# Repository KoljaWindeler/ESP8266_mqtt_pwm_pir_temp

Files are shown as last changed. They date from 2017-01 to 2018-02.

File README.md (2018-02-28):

# ESP8266 MQTT Repository

### Folderstructure

HA - Backup of my Homeassistant settings

JKW_MQTT_PWM_PIR_TEMP - The big deal, this is the firmware for the esp units

PCB - Some selfbuild boards based on the esp8266

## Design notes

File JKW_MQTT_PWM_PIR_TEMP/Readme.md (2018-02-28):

V1,V2,V3 are obsolete<br />
V4 is sort of the stable "branch" (killer feature was the peripheral framework)<br />
V5 is the development branch (new feature is the pseudo mesh structure)

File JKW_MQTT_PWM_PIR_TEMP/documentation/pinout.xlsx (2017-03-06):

Pin | Ard | Function | Note | Sonoff Inline box (assumption) | Zwischenstecker | Koljas Platine v2 | Koljas Platine v3
1 | - | VCC |  | - | - | - | -
2 | - | antenna |  | - | - | - | -
3 | - | VCC |  | - | - | - | -
4 | - | VCC |  | - | - | - | -
5 | - | rtc-vcc |  | - | - | - | -
6 | A0 | tout |  | nur MCU pin | nur MCU pin |  | Analog measurement
7 | - | e-en | 10k pullup, keine Weiterverwendung moeglich | - | - | - | -
8 | D0 | xpd-DCDC/GP16 | Deepsleepwakeup | - | - | - | PWM dimming 3
9 | D5 | SCL/MTMS/GP14 |  | an der Pfostenleiste (PIR) | nur MCU Pin | ? | PIR
10 | D6 | PWM0/MTDI/GP12 |  | am Relayschalter (Nmosfet) | zusatzlich LED1 | DS18B20 | am Relayschalter (Nmosfet)
11 | - | VCC |  | - | - | - | -
12 | D7 | PWM1/MTCK/GP13 | Useable as PWM out? | LED | LED (Modified DS18B20) | Relais | DS18B20
13 | D8 | PWM2/MTDO/GP15 | has to be low on startup! | 10k pulldown | 10k pulldown | 10k pulldown | 10k pulldown / Power for adc
14 | D4 | SDA/GP2 |  | nur MCU pin | nur MCU pin | DHT | DHT
15 | D3 | E-FW/SPICS2/GP0 |  | Pullup + S1 taster |  | switch | switch
16 | D2 | NC/GP4 |  | nur MCU pin | nur MCU pin | PWM dimming | PWM dimming 1
17 | - | VCC |  | - | - | - | -
18 | - | E-D2/GP9 | Flash | Flash | Flash | Flash | Flash
19 | - | E-D3/GP10 | Flash | Flash | Flash | Flash | Flash
20 | - | E-CMD/GP11 | Flash | Flash | Flash | Flash | Flash
21 | - | E-CLK/GP6 | Flash | Flash | Flash | Flash | Flash
22 | - | E-D0/GP7 | Flash | Flash | Flash | Flash | Flash
23 | - | E-D1/GP8 | Flash | Flash | Flash | Flash | Flash
24 | D1 | NC/GP5 |  | nur MCU pin (use a PIR?) | nur MCU pin (use a PIR?) | PIR | PWM dimming 2
25 | D9 | E-RX/GP3 | kann man nehmen wenn kein debug noetig ist | an Pfostenleiste, Uart | an Pfostenleiste, Uart | an Pfostenleiste, Uart | an Pfostenleiste, Uart
26 | D10 | E-TX/GP1 | kann man nehmen wenn kein debug noetig ist | an Pfostenleiste, Uart | an Pfostenleiste, Uart | an Pfostenleiste, Uart | an Pfostenleiste, Uart
27 | - | CLk |  | - | - | - | -
28 | - | CLK |  | - | - | - | -
29 | - | VCC |  | - | - | - | -
30 | - | VCC |  | - | - | - | -
31 | - | Res12k |  | - | - | - | -
32 | - | E-RST | 10k pullup, keine Weiterverwendung | - | - | - | -
33 |  | GND

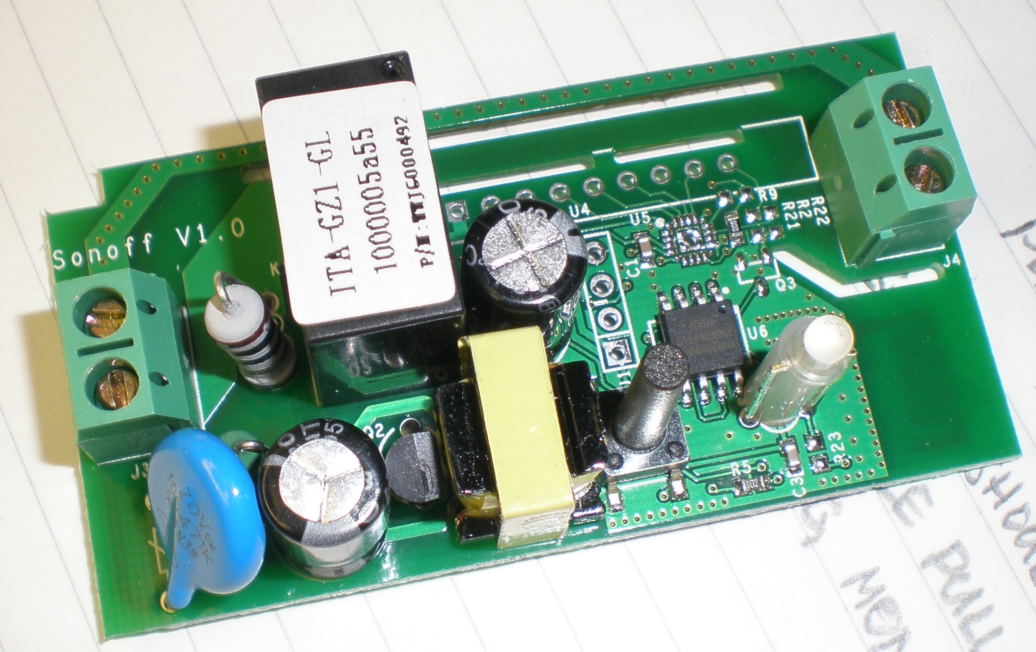
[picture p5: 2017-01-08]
JKW_MQTT_PWM_PIR_TEMP/documentation/sonoff_v1-top-oblique.png

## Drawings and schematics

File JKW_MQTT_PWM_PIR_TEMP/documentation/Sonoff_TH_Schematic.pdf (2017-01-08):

# VCC-3V3 E-FW

# VCC-3V3

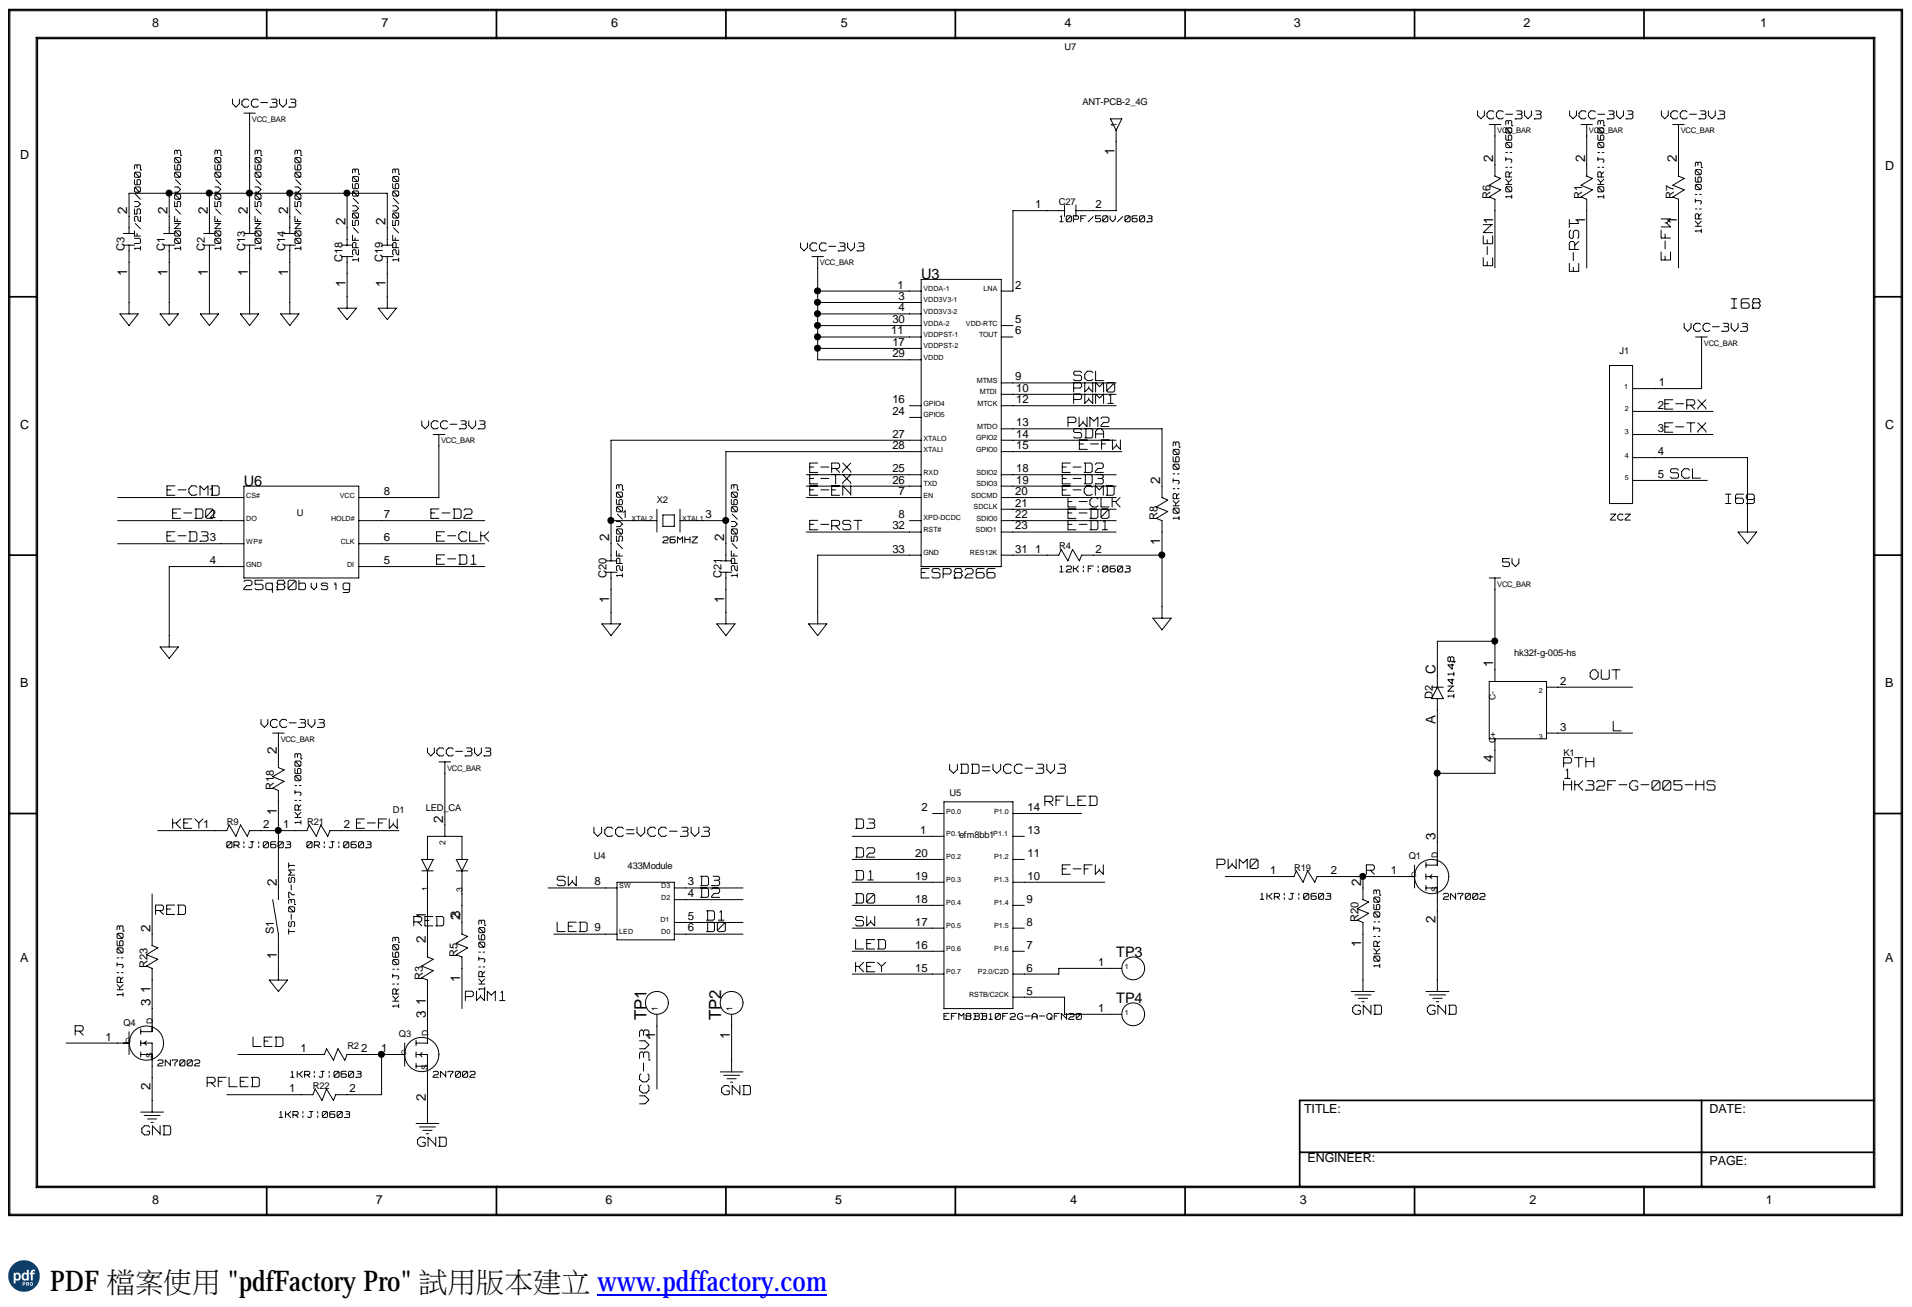
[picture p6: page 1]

TITLE: | DATE:

ENGINEER: | PAGE:

PDF 檔案使用 "pdfFactory Pro" 試用版本建立 www.pdffactory.com

330UH/0410

L1

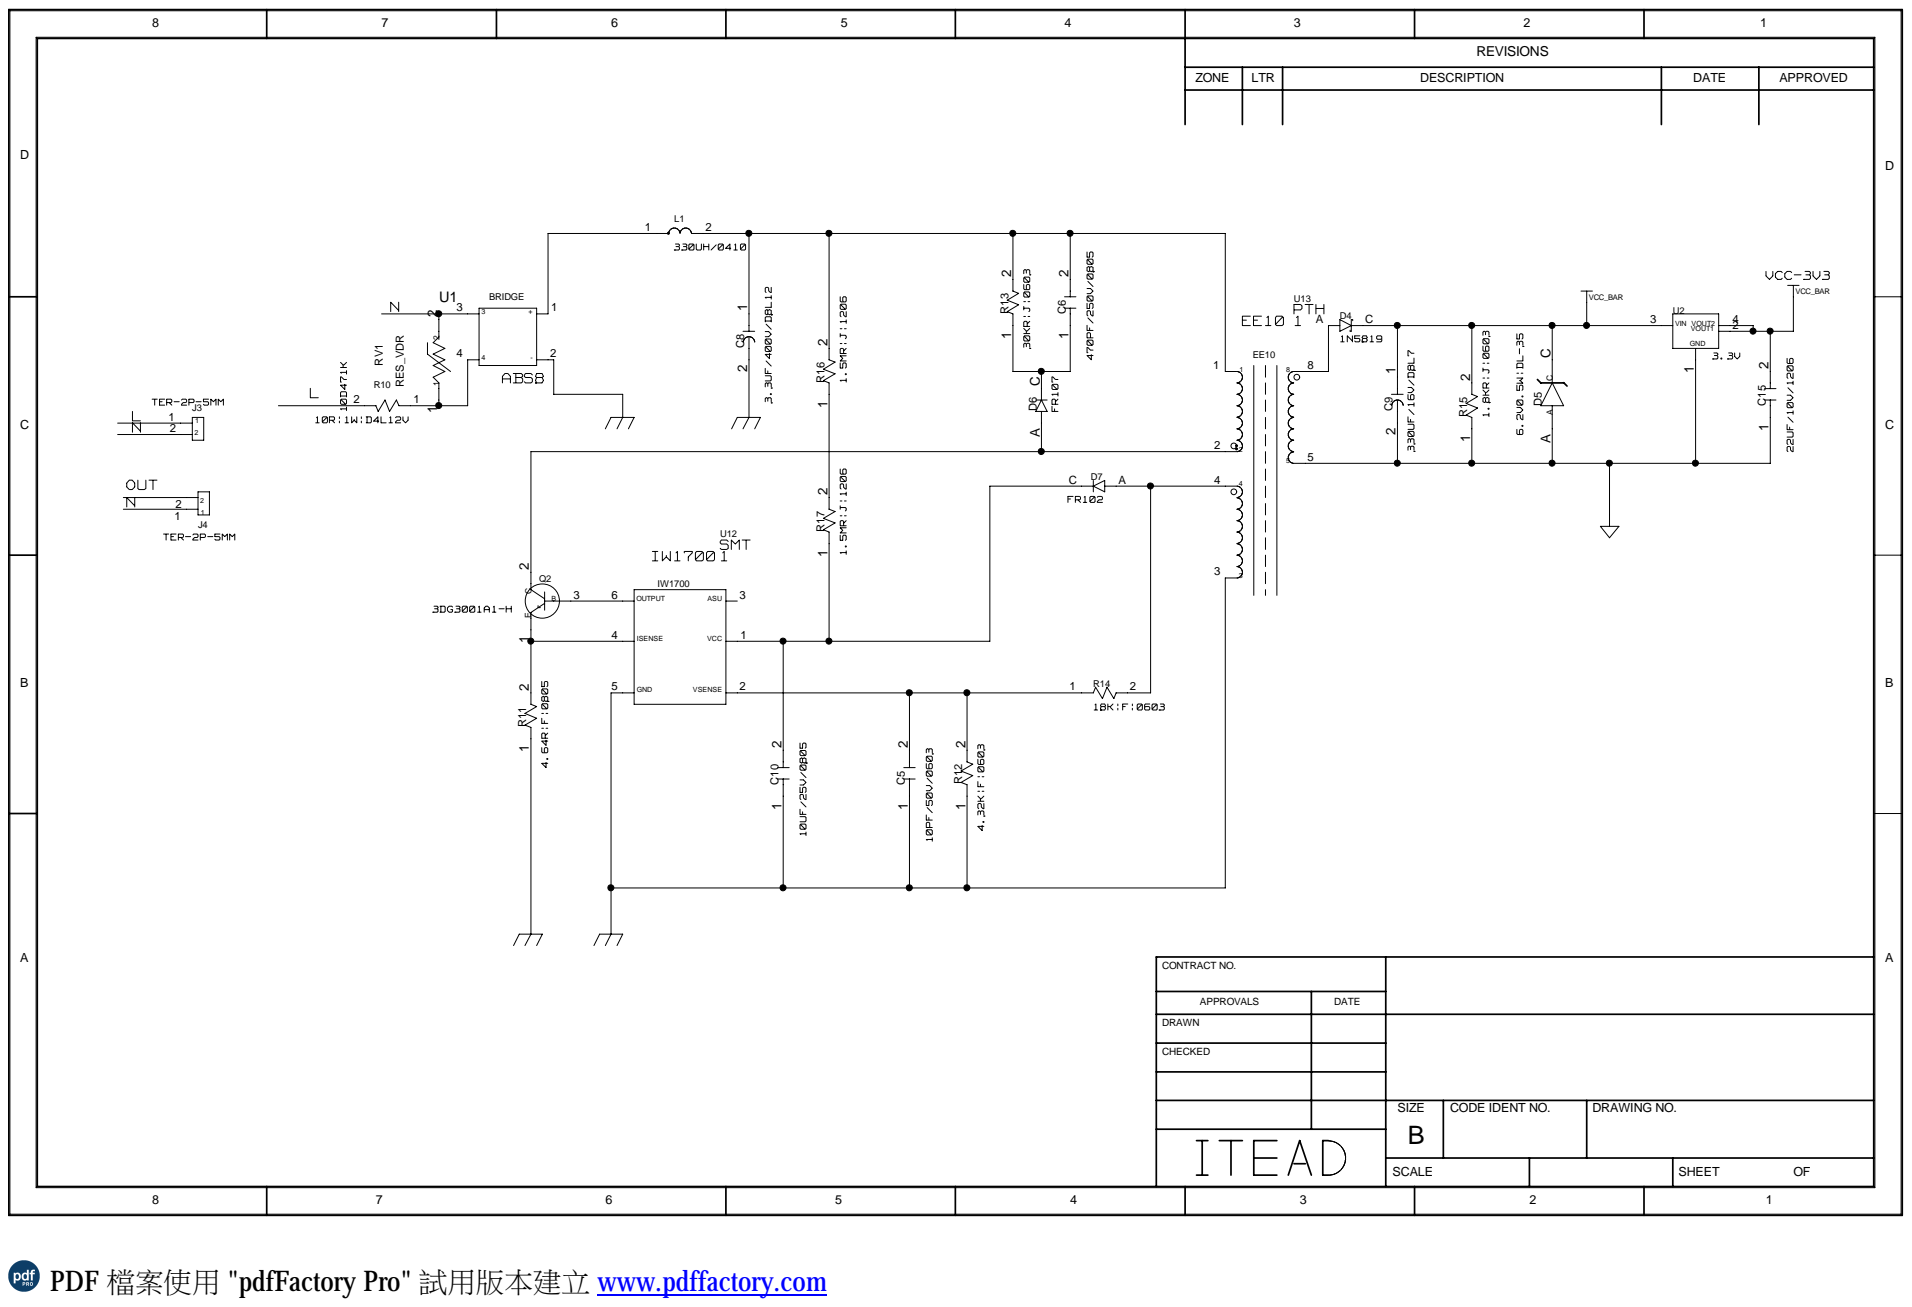
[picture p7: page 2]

PDF 檔案使用 "pdfFactory Pro" 試用版本建立 www.pdffactory.com

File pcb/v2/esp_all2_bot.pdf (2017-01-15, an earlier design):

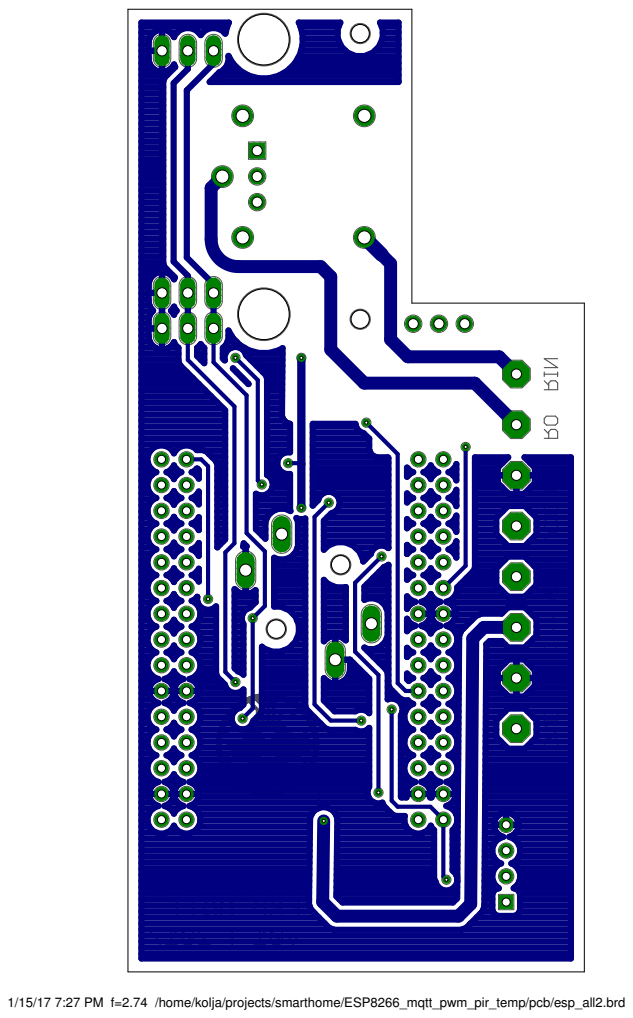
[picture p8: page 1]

1/15/17 7:27 PM f=2.74 /home/kolja/projects/smarthome/ESP8266_mqtt_pwm_pir_temp/pcb/esp_all2.brd

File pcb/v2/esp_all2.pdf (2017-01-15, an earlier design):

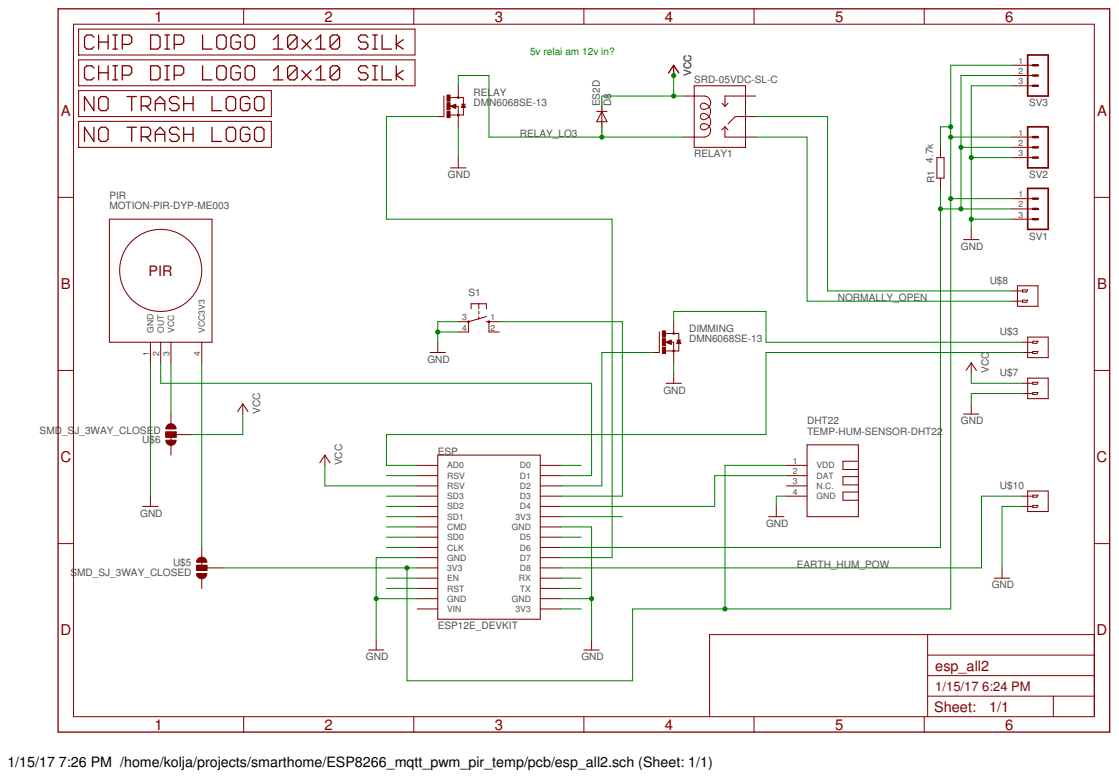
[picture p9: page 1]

1/15/17 7:26 PM /home/kolja/projects/smarthome/ESP8266_mqtt_pwm_pir_temp/pcb/esp_all2.sch (Sheet: 1/1)

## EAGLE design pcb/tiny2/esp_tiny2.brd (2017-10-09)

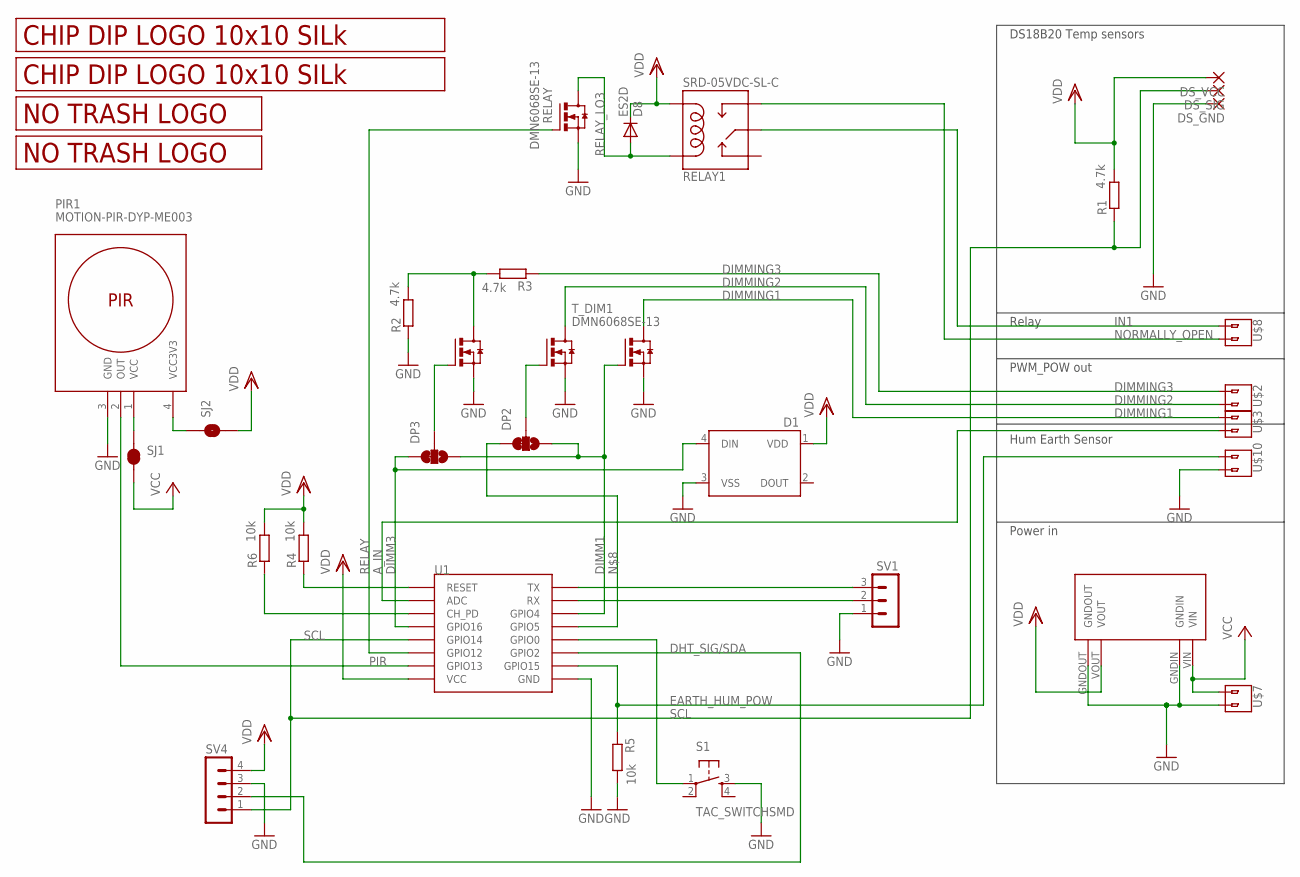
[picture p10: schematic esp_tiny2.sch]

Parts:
D1: WS2812B
D8: ES2D; SMB
DP2, DP3: SMD_SJ_3WAY_CLOSED
DS_GND: SMD2; SMD1,27-2,54
DS_SIG: SMD2; SMD1,27-2,54
DS_VCC: SMD2; SMD1,27-2,54
PIR1: MOTION-PIR-DYP-ME003; MOTION-PIR-DYP-ME003_FRAMELESS
R1, R2, R3: 4.7k; M0805
R4, R5, R6: 10k; M0805
RELAY: DMN6068SE-13; SOT223
RELAY1: SRD-05VDC-SL-C
S1: TAC_SWITCHSMD; TACTILE-SWITCH-SMD
SJ1: SMD_SJ_2WAY_CLOSEDCLOSED; SMD_SJ_2WAY_CLOSED
SJ2: SMD_SJ_2WAY_OPEN
SV1: MA03-1
SV4: MA04-1
T_DIM1, T_DIM2, T_DIM3: DMN6068SE-13; SOT223
U1: ESP12SMD; ESP12-SMD
U$1, U$11: LOGO_10X10_SILK; LOGO2_10X10_SILK
U$2, U$3, U$7, U$8, U$10: V1; 2_SCREW_PIN
U$4: LOGO_NO_TRASHNO_TRASH; LOGO_ROHS_NO_TRASH
U$9: LOGO_NO_TRASHROHS; LOGO_ROHS_SYM
U$12: MP1584EN

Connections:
3.3V_PIR: PIR1.4 (VCC3V3), SJ2.1
12V_PIR: PIR1.1 (VCC), SJ1.1
A_IN: U1.ADC, U$3.P$2 (2)
DHT_SIG/SDA: SV4.2, U1.GPIO2
DIMM1: DP2.3, DP3.3, T_DIM1.1 (G), U1.GPIO4
DIMM3: D1.4 (DIN), DP3.1, U1.GPIO16
DIMMING1: T_DIM1.2 (D), T_DIM1.4 (D), U$3.P$1 (1)
DIMMING2: T_DIM2.2 (D), T_DIM2.4 (D), U$2.P$2 (2)
DIMMING3: R3.1, U$2.P$1 (1)
EARTH_HUM_POW: R5.1, U1.GPIO15, U$10.P$1 (1)
GND: D1.3 (VSS), DS_GND.1, PIR1.3 (GND), R2.1, R5.2, RELAY.3 (S), S1.3, SV1.1, SV4.3, T_DIM1.3 (S), T_DIM2.3 (S), T_DIM3.3 (S), U1.GND, U$7.P$2 (2), U$10.P$2 (2), U$12.GNDIN, U$12.GNDOUT
IN1: RELAY1.SWCOMMON, U$8.P$1 (1)
unnamed: R6.1, U1.CH_PD
unnamed: R4.1, U1.RESET
unnamed: R2.2, R3.2, T_DIM3.2 (D), T_DIM3.4 (D)
unnamed: SV1.3, U1.TXD0 (TX)
unnamed: SV1.2, U1.RXD0 (RX)
unnamed: S1.1, U1.GPIO0
unnamed: DP2.1, U1.GPIO5
unnamed: DP3.2, T_DIM3.1 (G)
unnamed: DP2.2, T_DIM2.1 (G)
NORMALLY_OPEN: RELAY1.SWOPEN, U$8.P$2 (2)
PIR: PIR1.2 (OUT), U1.GPIO13
RELAY: RELAY.1 (G), U1.GPIO12
RELAY_LO3: D8.A, RELAY.2 (D), RELAY.4 (D), RELAY1.COIL1
SCL: DS_SIG.1, R1.1, SV4.1, U1.GPIO14
VCC: SJ1.3, U$7.P$1 (1), U$12.VIN
VDD: D1.1 (VDD), D8.C, DS_VCC.1, R1.2, R4.2, R6.2, RELAY1.COIL0, SJ2.3, SV4.4, U1.VCC, U$12.VOUT

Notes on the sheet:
DS18B20 Temp sensors
Relay
PWM_POW out
Hum Earth Sensor
Power in

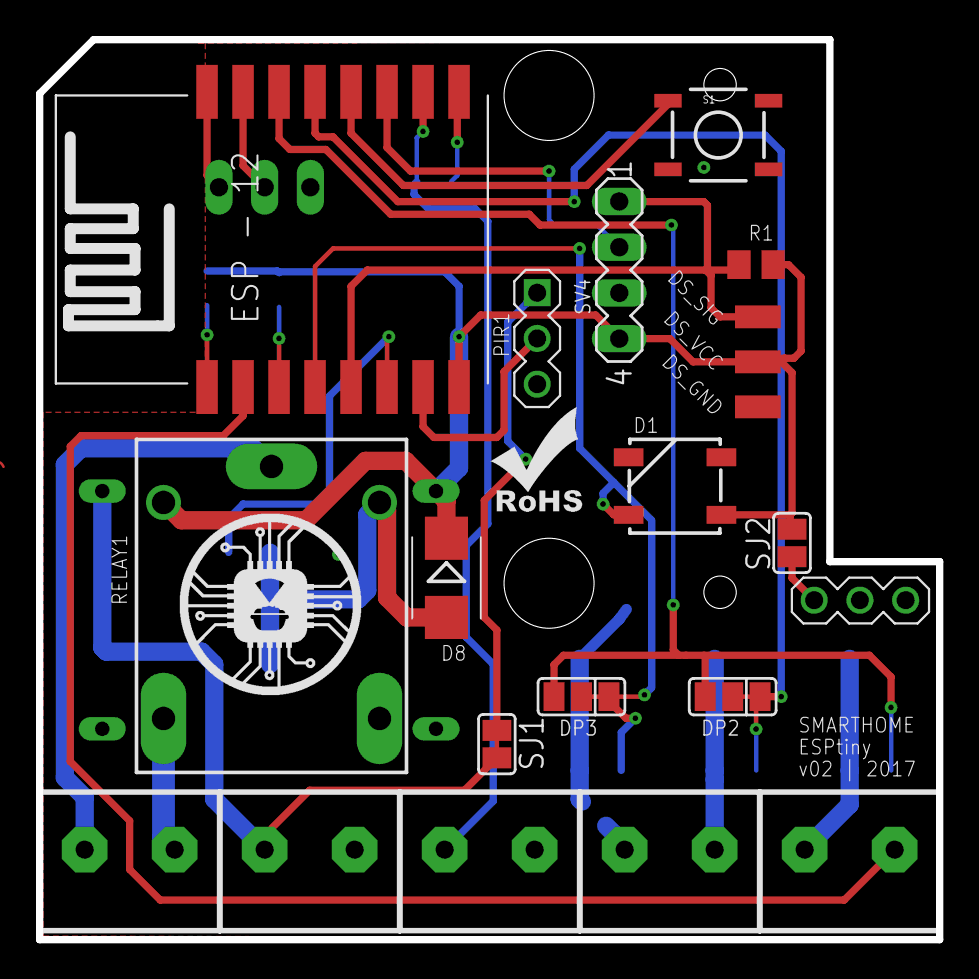
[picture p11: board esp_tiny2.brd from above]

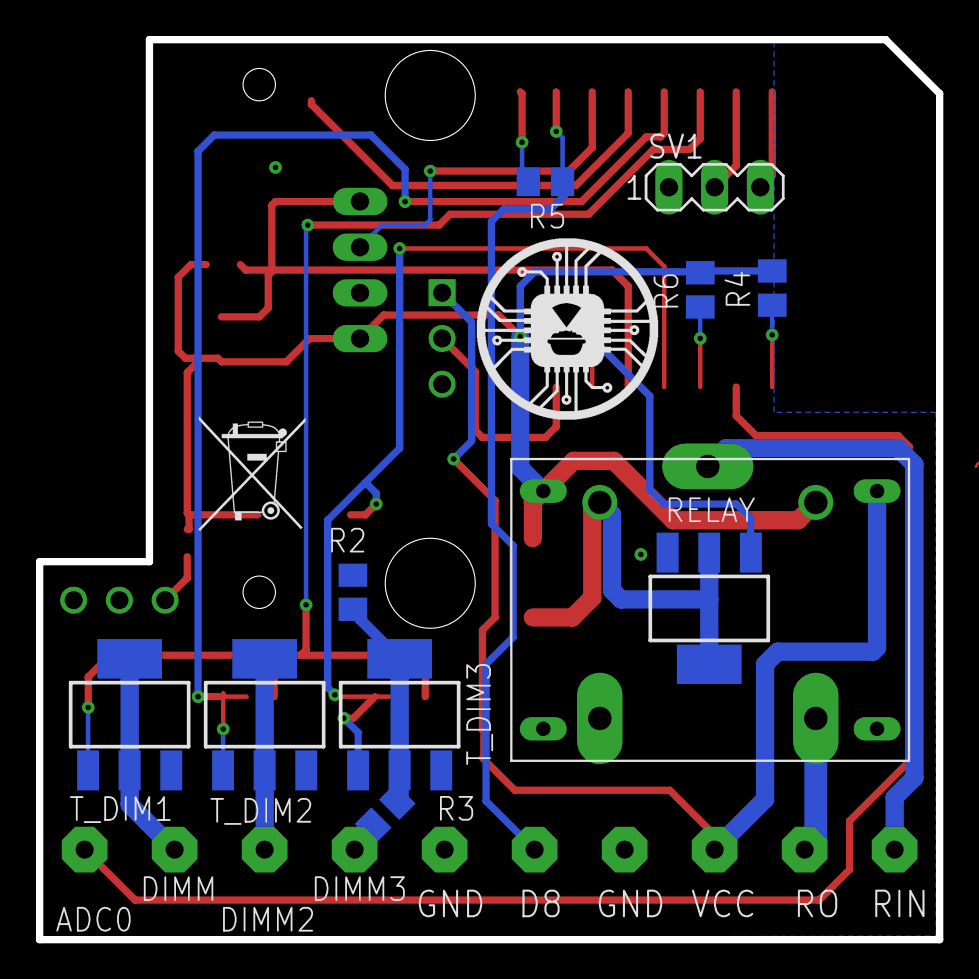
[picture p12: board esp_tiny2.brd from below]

Board: 2 copper layers, 50.0 x 50.0 mm, 35 parts (13 on the bottom side), 28 nets.

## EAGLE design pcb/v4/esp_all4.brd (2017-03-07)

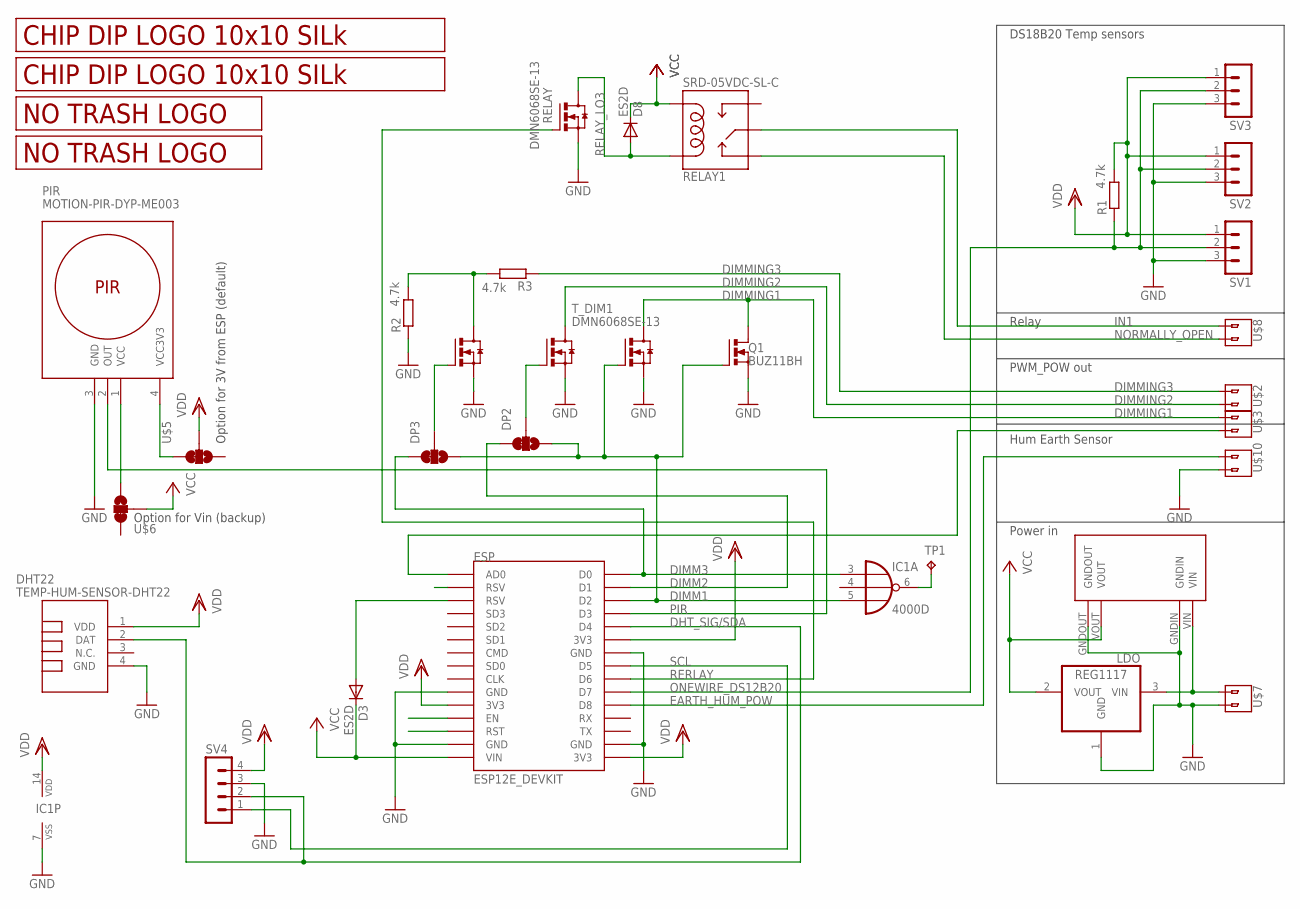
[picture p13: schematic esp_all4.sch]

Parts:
D3, D8: ES2D; SMB
DHT22: TEMP-HUM-SENSOR-DHT22
DP2, DP3: SMD_SJ_3WAY_CLOSED
ESP: ESP12E_DEVKIT
IC1: 4000D; SO14
LDO: REG1117; SOT223
PIR: MOTION-PIR-DYP-ME003
Q1: BUZ11BH; TO220BH
R1, R2, R3: 4.7k; M0805
RELAY: DMN6068SE-13; SOT223
RELAY1: SRD-05VDC-SL-C
SV1, SV2, SV3: MA03-1
SV4: MA04-1
TP1: TPTP20SQ; TP20SQ
T_DIM1, T_DIM2, T_DIM3: DMN6068SE-13; SOT223
U$1, U$11: LOGO_10X10_SILK; LOGO2_10X10_SILK
U$2, U$3, U$7, U$8, U$10: V1; 2_SCREW_PIN
U$4: LOGO_NO_TRASHNO_TRASH; LOGO_ROHS_NO_TRASH
U$5, U$6: SMD_SJ_3WAY_CLOSED
U$9: LOGO_NO_TRASHROHS; LOGO_ROHS_SYM
U$12: MP1584EN_FRAMELESS

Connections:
DHT_SIG/SDA: DHT22.2 (DAT), ESP.D4, ESP.D41 (D4), SV4.2
DIMM1: DP2.3, DP3.3, ESP.D2, ESP.D21 (D2), IC1.5 (I2), Q1.G, T_DIM1.1 (G)
DIMM2: DP2.1, ESP.D1, ESP.D11 (D1)
DIMM3: DP3.1, ESP.D0, ESP.D01 (D0), IC1.3 (I0)
DIMMING1: Q1.D, T_DIM1.2 (D), T_DIM1.4 (D), U$3.P$1 (1)
DIMMING2: T_DIM2.2 (D), T_DIM2.4 (D), U$2.P$2 (2)
DIMMING3: R3.1, U$2.P$1 (1)
EARTH_HUM_POW: ESP.D8, ESP.D81 (D8), U$10.P$1 (1)
GND: DHT22.4 (GND), ESP.GND@0 (GND), ESP.GND@1 (GND), ESP.GND@2 (GND), ESP.GND@3 (GND), ESP.GND@4 (GND), ESP.GND@5 (GND), ESP.GND@6 (GND), ESP.GND@7 (GND), IC1.7 (VSS), LDO.1 (GND), PIR.3 (GND), Q1.S, R2.1, RELAY.3 (S), SV1.3, SV2.3, SV3.3, SV4.3, T_DIM1.3 (S), T_DIM2.3 (S), T_DIM3.3 (S), U$7.P$2 (2), U$10.P$2 (2), U$12.GNDIN, U$12.GNDOUT
IN1: RELAY1.SWCOMMON, U$8.P$1 (1)
unnamed: ESP.AD0, ESP.AD1 (AD0), U$3.P$2 (2)
unnamed: ESP.RSV@0 (RSV), ESP.RSV@01 (RSV)
unnamed: R2.2, R3.2, T_DIM3.2 (D), T_DIM3.4 (D)
unnamed: IC1.6 (O), TP1.TP
unnamed: ESP.EN, ESP.EN1 (EN)
unnamed: ESP.RST, ESP.RST1 (RST)
unnamed: D3.A, ESP.RSV@1 (RSV), ESP.RSV@11 (RSV)
unnamed: LDO.3 (VIN), U$7.P$1 (1), U$12.VIN
unnamed: DP3.2, T_DIM3.1 (G)
unnamed: DP2.2, T_DIM2.1 (G)
unnamed: PIR.4 (VCC3V3), U$5.1
unnamed: PIR.1 (VCC), U$6.3
NORMALLY_OPEN: RELAY1.SWCLOSED (SWCLOSE), U$8.P$2 (2)
ONEWIRE_DS12B20: ESP.D7, ESP.D71 (D7), R1.1, SV1.2, SV2.2, SV3.2
PIR: ESP.D3, ESP.D31 (D3), PIR.2 (OUT)
RELAY_LO3: D8.A, RELAY.2 (D), RELAY.4 (D), RELAY1.COIL1
RERLAY: ESP.D6, ESP.D61 (D6), RELAY.1 (G)
SCL: ESP.D5, ESP.D51 (D5), SV4.1
VCC: D3.C, D8.C, ESP.VIN, ESP.VIN1 (VIN), LDO.2 (VOUT), RELAY1.COIL0, U$6.2, U$12.VOUT
VDD: DHT22.1 (VDD), ESP.3V3@0 (3V3), ESP.3V3@1 (3V3), ESP.3V3@2 (3V3), ESP.3V3@3 (3V3), ESP.3V3@4 (3V3), ESP.3V3@5 (3V3), IC1.14 (VDD), R1.2, SV1.1, SV2.1, SV3.1, SV4.4, U$5.2

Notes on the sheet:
DS18B20 Temp sensors
Relay
PWM_POW out
Hum Earth Sensor
Power in
Option for 3V from ESP (default)
Option for Vin (backup)

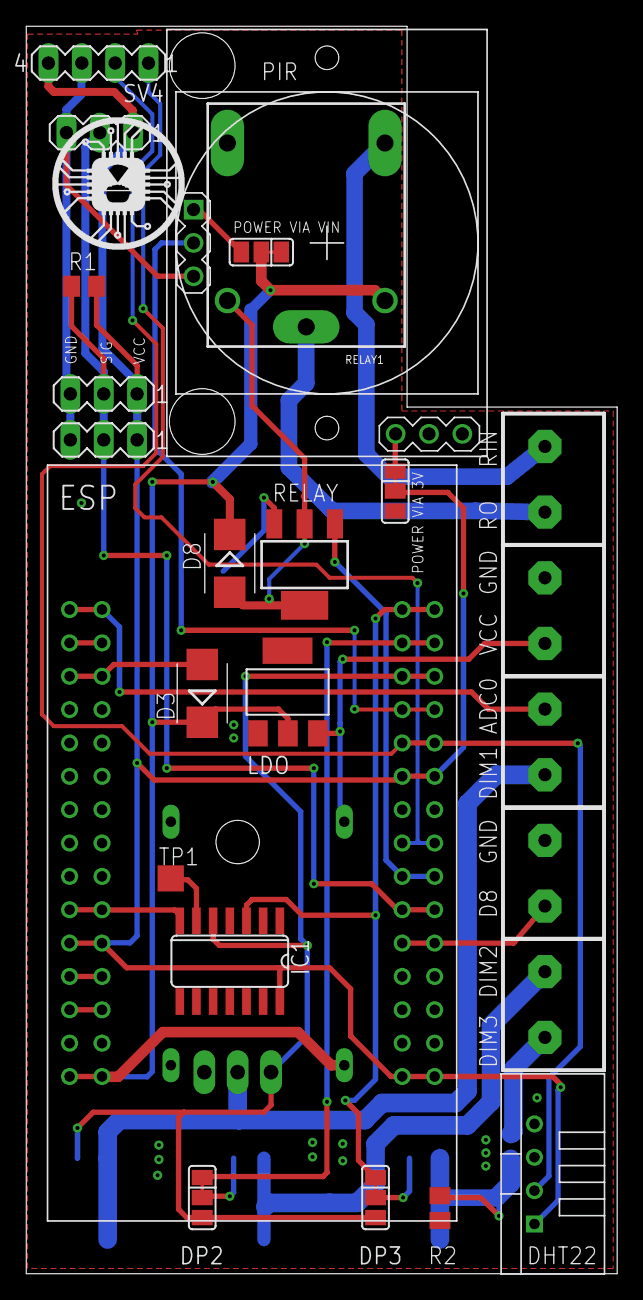
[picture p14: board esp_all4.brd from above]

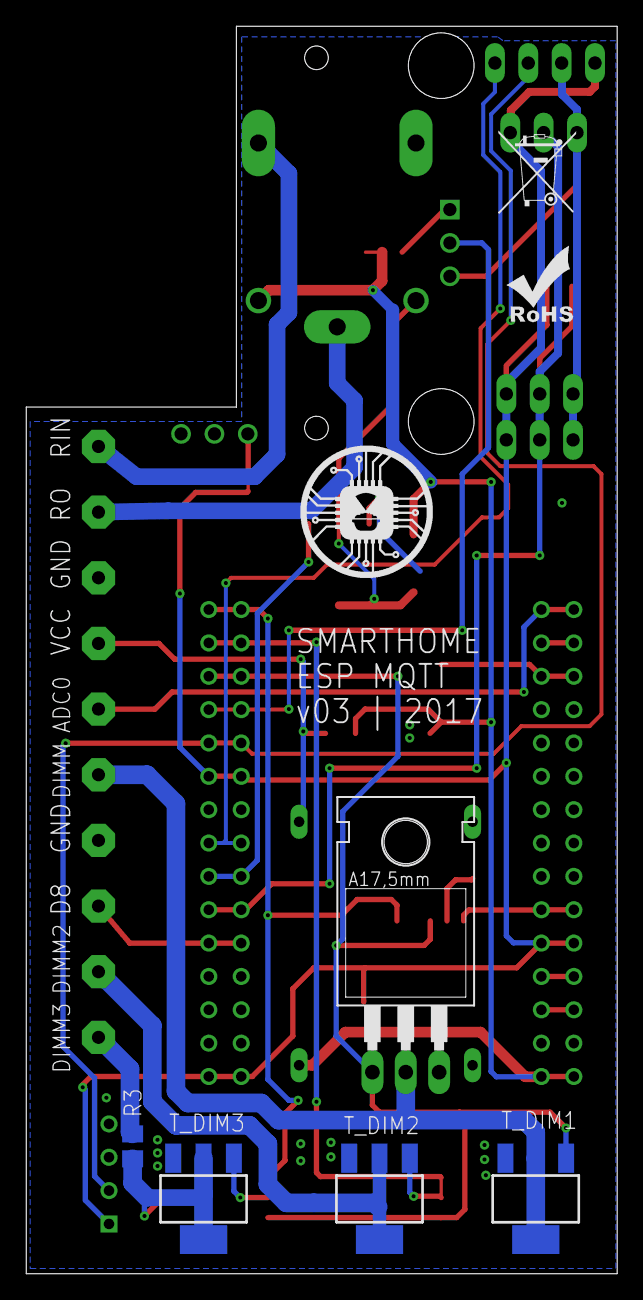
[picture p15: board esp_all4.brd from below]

Board: 2 copper layers, 45.0 x 95.0 mm, 35 parts (9 on the bottom side), 30 nets.

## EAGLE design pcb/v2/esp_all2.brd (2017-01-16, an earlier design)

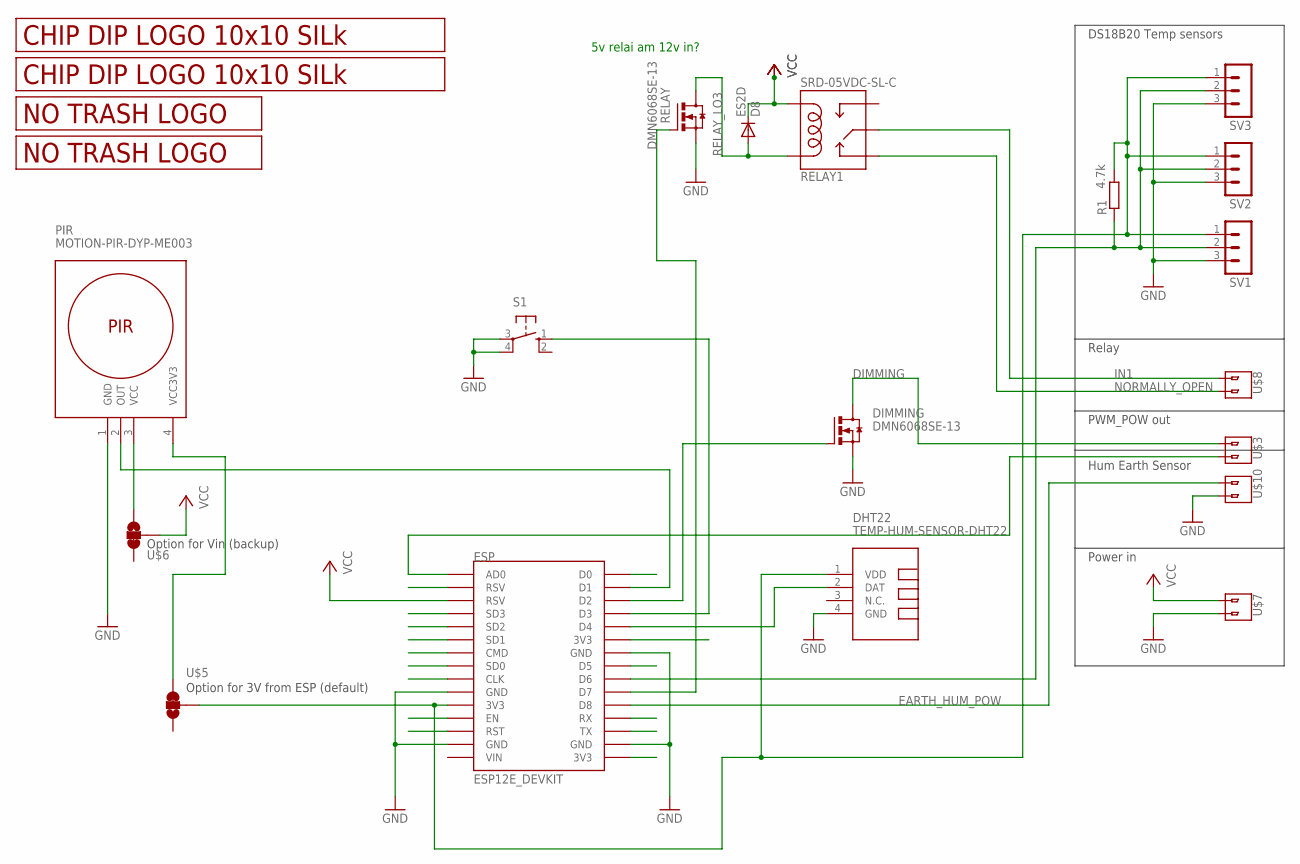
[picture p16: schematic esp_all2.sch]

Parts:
D8: ES2D; SMB
DHT22: TEMP-HUM-SENSOR-DHT22
DIMMING: DMN6068SE-13; SOT223
ESP: ESP12E_DEVKIT
PIR: MOTION-PIR-DYP-ME003
R1: 4.7k; M0805
RELAY: DMN6068SE-13; SOT223
RELAY1: SRD-05VDC-SL-C
S1: 40/XX; B3F/40XX
SV1, SV2, SV3: MA03-1
U$1, U$11: LOGO_10X10_SILK; LOGO2_10X10_SILK
U$3, U$7, U$8, U$10: V1; 2_SCREW_PIN
U$4: LOGO_NO_TRASHNO_TRASH; LOGO_ROHS_NO_TRASH
U$5, U$6: SMD_SJ_3WAY_CLOSED
U$9: LOGO_NO_TRASHROHS; LOGO_ROHS_SYM

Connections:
DIMMING: DIMMING.2 (D), DIMMING.4 (D), U$3.P$1 (1)
EARTH_HUM_POW: ESP.D8, ESP.D81 (D8), U$10.P$1 (1)
GND: DHT22.4 (GND), DIMMING.3 (S), ESP.GND@0 (GND), ESP.GND@1 (GND), ESP.GND@2 (GND), ESP.GND@3 (GND), ESP.GND@4 (GND), ESP.GND@5 (GND), ESP.GND@6 (GND), ESP.GND@7 (GND), PIR.1 (GND), RELAY.3 (S), S1.3, S1.4 (P1), SV1.3, SV2.3, SV3.3, U$7.P$2 (2), U$10.P$2 (2)
IN1: RELAY1.SWCOMMON, U$8.P$1 (1)
unnamed: ESP.AD0, ESP.AD1 (AD0), U$3.P$2 (2)
unnamed: ESP.RSV@0 (RSV), ESP.RSV@01 (RSV)
unnamed: ESP.SD3, ESP.SD32 (SD3)
unnamed: ESP.SD2, ESP.SD22 (SD2)
unnamed: ESP.SD1, ESP.SD12 (SD1)
unnamed: ESP.CMD, ESP.CMD1 (CMD)
unnamed: ESP.SD0, ESP.SD01 (SD0)
unnamed: ESP.CLK, ESP.CLK1 (CLK)
unnamed: ESP.D7, ESP.D71 (D7), RELAY.1 (G)
unnamed: ESP.EN, ESP.EN1 (EN)
unnamed: ESP.RST, ESP.RST1 (RST)
unnamed: ESP.D6, ESP.D61 (D6), R1.1, SV1.2, SV2.2, SV3.2
unnamed: ESP.TX, ESP.TX1 (TX)
unnamed: ESP.RX, ESP.RX1 (RX)
unnamed: ESP.D5, ESP.D51 (D5)
unnamed: PIR.4 (VCC3V3), U$5.1
unnamed: DHT22.1 (VDD), ESP.3V3@0 (3V3), ESP.3V3@3 (3V3), ESP.3V3@4 (3V3), ESP.3V3@5 (3V3), R1.2, SV1.1, SV2.1, SV3.1, U$5.2
unnamed: DHT22.2 (DAT), ESP.D4, ESP.D41 (D4)
unnamed: ESP.D3, ESP.D31 (D3), S1.1 (S)
unnamed: DIMMING.1 (G), ESP.D2, ESP.D21 (D2)
unnamed: ESP.D1, ESP.D11 (D1), PIR.2 (OUT)
unnamed: ESP.D0, ESP.D01 (D0)
unnamed: PIR.3 (VCC), U$6.3
NORMALLY_OPEN: RELAY1.SWCLOSED (SWCLOSE), U$8.P$2 (2)
RELAY_LO3: D8.A, RELAY.2 (D), RELAY.4 (D), RELAY1.COIL1
VCC: D8.C, ESP.RSV@1 (RSV), ESP.RSV@11 (RSV), RELAY1.COIL0, U$6.2, U$7.P$1 (1)

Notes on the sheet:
5v relai am 12v in?
DS18B20 Temp sensors
Relay
PWM_POW out
Hum Earth Sensor
Power in
Option for 3V from ESP (default)
Option for Vin (backup)

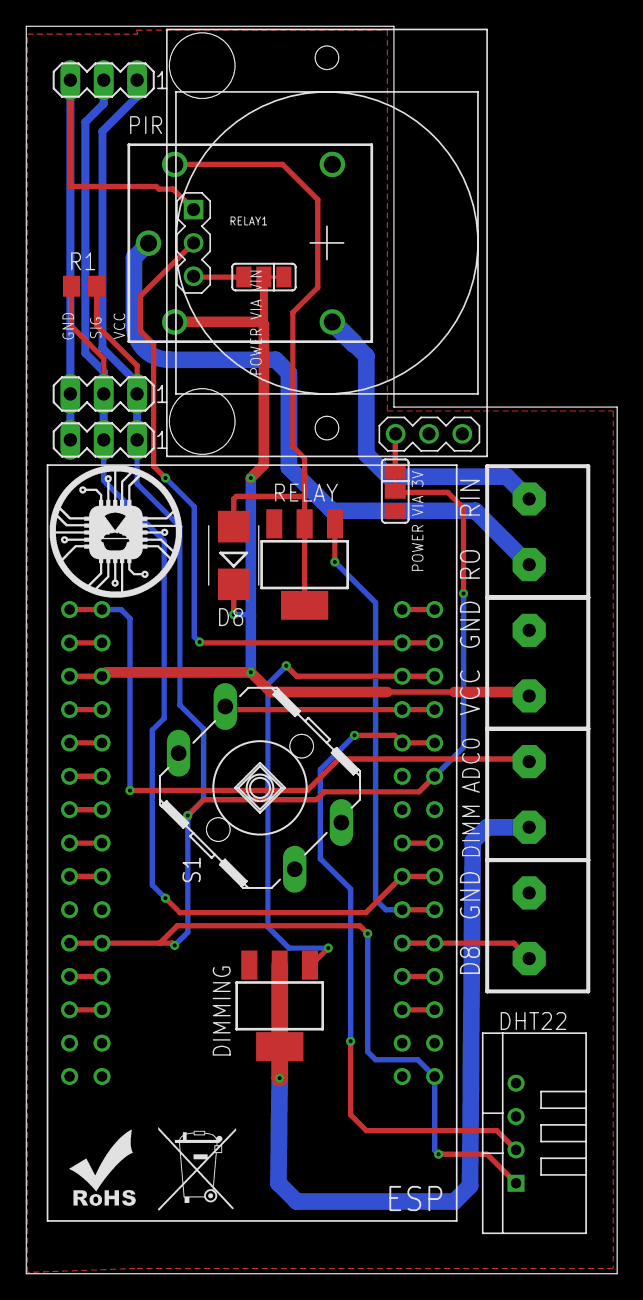
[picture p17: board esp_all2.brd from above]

Board: 2 copper layers, 45.0 x 95.0 mm, 22 parts (1 on the bottom side), 30 nets.

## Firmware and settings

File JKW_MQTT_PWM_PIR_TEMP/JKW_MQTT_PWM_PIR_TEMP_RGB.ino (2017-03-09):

/*
	Highly based on a combination of different version of
	https://github.com/mertenats/Open-Home-Automation/tree/master/ha_mqtt_binary_sensor_pir
	Also using https://github.com/tzapu/WiFiManager

	Configuration (HA) :
	  light:
	  
	 #######  single CHANNEL ################### 
  - platform: mqtt ### tower living
    name: "dev1"
    state_topic: "dev1/PWM_light/status"
    command_topic: "dev1/PWM_dimm/switch"
    brightness_state_topic: 'dev1/PWM_light/brightness'
	## use the line below for dimming
	brightness_command_topic: 'dev1/PWM_dimm/brightness/set'
	## use the line below for setting hard 
	# brightness_command_topic: 'dev1/PWM_light/brightness/set'
    qos: 0
    payload_on: "ON"
    payload_off: "OFF"
    optimistic: false
    brightness_scale: 99
	#######  single CHANNEL ###################
	#######  rgb CHANNEL ################### 
  - platform: mqtt ### tower living
    name: "dev1"
    state_topic: "dev1/PWM_light/status"
    command_topic: "dev1/PWM_dimm/switch"
    brightness_state_topic: 'dev1/PWM_light/brightness'
	rgb_state_topic: 'dev1/PWM_RGB_dimm/color/set'
	## use the lines below for dimming
    brightness_command_topic: 'dev1/PWM_dimm/brightness/set'
	rgb_command_topic: 'dev1/PWM_RGB_dimm/color/set'
	## use the lines below for setting
	# brightness_command_topic: 'dev1/PWM_light/brightness/set'
	# rgb_command_topic: 'dev1/PWM_RGB_light/color/set'
    qos: 0
    payload_on: "ON"
    payload_off: "OFF"
    optimistic: false
    brightness_scale: 99
	#######  rgb CHANNEL ###################

  config for sonoff modules:
  generic 8266
  DIO flash mode
  flash 40 mhz, cpu 80mhz 
  flash size 1mb, 64k filesystem

  This sketch (2017/01/21): 333k (Basic wifi sketch 230k)

  requires arduino libs:
  - adafruit unified sensor
  - adafruit dht22
  - onewire
*/

#include <ESP8266WiFi.h>
#include "WiFiManager.h" // local modified version          //https://github.com/tzapu/WiFiManager WiFi Configuration Magic
#include <PubSubClient.h>
#include <OneWire.h>
#include <EEPROM.h>
#include <DHT.h>
#include <Wire.h>

//////////////////////////////////////////////////// defines //////////////////////////////////////////////
#define SERIAL_DEBUG
#define DIMM_DONE 	        0 // state defs
#define DIMM_DIMMING 	      1 // state defs
#define DHT_def             1
#define DS_def              2
#define CONFIG_SSID         "OPEN_ESP_CONFIG_AP" // SSID of the configuration mode
#define MAX_AP_TIME         300 // restart eps after 300 sec in config mode
#define TEMP_MAX            50 // DS18B20 repoorts 85.0 on first reading ... for whatever reason
// pins
#define PINOUT_SONOFF 1     // set this to "#define" for the sonoff
//#define PINOUT_KOLJA_V2         // set this to "#define" for the pcb firmware .. incosistent pinout
// D8 war nicht so gut ... startet nicht mehr 
#ifdef PINOUT_SONOFF
	#define SIMPLE_LIGHT_PIN  12 // D6
	#define DS_PIN            13 // D7
  #define PIR_PIN           14 // D5
#endif 
#ifdef PINOUT_KOLJA_V2
	#define SIMPLE_LIGHT_PIN  13 // D7
	#define DS_PIN            12 // D6
  #define PIR_PIN            5 // D1
#endif 
#define PWM_LIGHT_PIN1       4  // D2
#define PWM_LIGHT_PIN2       5  // D1
#define PWM_LIGHT_PIN3       16  // D0

#define BUTTON_INPUT_PIN    0  // D3
#define DHT_PIN             2  // D4
#define GPIO_D8             15 // D8


#define BUTTON_TIMEOUT      1500 // max 1500ms timeout between each button press to count up (start of config)
#define BUTTON_DEBOUNCE     200 // ms debouncing for the botton
#define MSG_BUFFER_SIZE     60 // mqtt messages max char size

#define TOTAL_PERIODIC_SLOTS  5 // 5 sensors: adc, rssi, dht_hum, dht_temp, ds18b20
#define UPDATE_PERIODIC       60000/TOTAL_PERIODIC_SLOTS // update temperature once per minute .. but with 5 sensors we have to be faster
#define PUBLISH_TIME_OFFSET   200 // ms timeout between two publishes
#define UPDATE_PIR            900000L // ms timeout between two publishes of the pir .. needed?

// Buffer to hold data from the WiFi manager for mqtt login
struct mqtt_data { //80 byte
  char login[16];
  char pw[16];
  char dev_short[6];
  char server_cli_id[20];
  char server_ip[16];
  char server_port[6];
};

struct led {
  uint8_t r;
  uint8_t g;
  uint8_t b;
};
//////////////////////////////////////////////////// globals //////////////////////////////////////////////

DHT dht(DHT_PIN, DHT22); // DHT22
OneWire ds(DS_PIN);  // on digital pin DHT_DS_PIN

char char_buffer[35];

// MQTT: topics, constants, etc
const PROGMEM char*     MQTT_PWM_LIGHT_STATE_TOPIC              = "/PWM_light/status";		      // publish state here ON / OFF
const PROGMEM char*     MQTT_PWM_LIGHT_COMMAND_TOPIC	  	      = "/PWM_light/switch"; 		      // get command here ON / OFF

const PROGMEM char*     MQTT_SIMPLE_LIGHT_STATE_TOPIC		        = "/simple_light/status";	      // publish state here ON / OFF
const PROGMEM char*     MQTT_SIMPLE_LIGHT_COMMAND_TOPIC		      = "/simple_light/switch"; 	    // get command here ON / OFF

const PROGMEM char*     MQTT_PWM_LIGHT_BRIGHTNESS_STATE_TOPIC   = "/PWM_light/brightness";		  // publish 0-99
const PROGMEM char*     MQTT_PWM_LIGHT_BRIGHTNESS_COMMAND_TOPIC = "/PWM_light/brightness/set";	// set value 0-99
const PROGMEM char*     MQTT_PWM_DIMM_COMMAND_TOPIC             = "/PWM_dimm/switch";           // get ON/OFF command here

const PROGMEM char*     MQTT_PWM_RGB_DIMM_COLOR_STATE_TOPIC   = "/PWM_RGB_light/color";		  // publish value "0-99,0-99,0-99"
const PROGMEM char*     MQTT_PWM_RGB_COLOR_COMMAND_TOPIC   = "/PWM_RGB_light/color/set";		  // set value "0-99,0-99,0-99"
const PROGMEM char*     MQTT_PWM_RGB_DIMM_COLOR_COMMAND_TOPIC   = "/PWM_RGB_dimm/color/set";		  // set value "0-99,0-99,0-99"

const PROGMEM char*     MQTT_PWM_DIMM_DELAY_COMMAND_TOPIC 	    = "/PWM_dimm/delay/set";		    // set value
const PROGMEM char*     MQTT_PWM_DIMM_BRIGHTNESS_COMMAND_TOPIC 	= "/PWM_dimm/brightness/set";	  // set value

const PROGMEM char* 	  MQTT_MOTION_STATUS_TOPIC		            = "/motion/status";			        // publish
const PROGMEM char* 	  MQTT_TEMPARATURE_DS_TOPIC               = "/temperature_DS";	          // publish
const PROGMEM char*     MQTT_TEMPARATURE_DHT_TOPIC              = "/temperature_DHT";           // publish
const PROGMEM char* 	  MQTT_HUMIDITY_DHT_TOPIC			            = "/humidity_DHT";	            // publish
const PROGMEM char*     MQTT_RSSI_STATE_TOPIC                   = "/rssi";                      // publish
const PROGMEM char*     MQTT_ADC_STATE_TOPIC                    = "/adc";                       // publish

const PROGMEM char*     STATE_ON          		= "ON";
const PROGMEM char*     STATE_OFF         		= "OFF";

// variables used to store the state and the brightness of the light
boolean		m_pwm_light_state = false;
boolean		m_published_pwm_light_state = true; // to force instant publish once we are online
boolean		m_simple_light_state = false;
boolean		m_published_simple_light_state = true; // to force instant publish once we are online

led		m_light_target		=  {99,99,99};
led		m_light_start		= 	{99,99,99};
led		m_light_current	=  {99,99,99};
led		m_light_backup	=  {99,99,99};

// converts from half log to linear .. the human eye is a smartass
uint8_t     intens[100] = {0,1,2,3,4,5,6,7,8,9,10,11,12,13,14,15,16,17,18,19,20,21,22,23,24,25,26,27,27,28,29,30,31,32,33,34,35,36,38,39,40,41,43,44,45,47,48,50,51,53,55,57,58,60,62,64,66,68,70,73,75,77,80,82,85,88,91,93,96,99,103,106,109,113,116,120,124,128,132,136,140,145,150,154,159,164,170,175,181,186,192,198,205,211,218,225,232,239,247,255};

uint8_t     	m_published_light_brightness = 1; // to force instant publish once we are online
uint8_t     	m_light_brightness = 0; // to force instant publish once we are online
uint16_t     m_published_light_color = 1; // to force instant publish once we are online (sum of rgb)
uint16_t	m_pwm_dimm_time = 10; // 10ms per Step, 255*0.01 = 2.5 sec
uint8_t 		m_pir_state = LOW; // inaktiv
uint8_t 		m_published_pir_state = HIGH; // to force instant publish once we are online

// buffer used to send/receive data with MQTT, can not be done with the char_buffer, as both as need simultaniously 
char                  m_msg_buffer[MSG_BUFFER_SIZE];
WiFiClient            wifiClient;
WiFiManager 		      wifiManager;
PubSubClient          client(wifiClient);
mqtt_data             mqtt;

// prepare wifimanager variables
WiFiManagerParameter  WiFiManager_mqtt_server_ip("mq_ip", "mqtt server ip", "", 15);
WiFiManagerParameter  WiFiManager_mqtt_server_port("mq_port", "mqtt server port", "1883", 5);
WiFiManagerParameter  WiFiManager_mqtt_client_short("sid", "mqtt short id", "devXX", 6);
WiFiManagerParameter  WiFiManager_mqtt_client_id("cli_id", "mqtt client id", "18 char long desc.", 19);
WiFiManagerParameter  WiFiManager_mqtt_server_login("login", "mqtt login", "", 15);
WiFiManagerParameter  WiFiManager_mqtt_server_pw("pw", "mqtt pw", "", 15);


uint32_t 	updateFastValuesTimer	= 0;
uint32_t        updateSlowValuesTimer   = 0;
uint32_t 	timer_dimmer	= 0;
uint32_t 	timer_dimmer_start	= 0;
uint32_t 	timer_dimmer_end	= 0;
uint32_t        timer_button_down  = 0;
uint8_t         counter_button = 0;
uint32_t        timer_last_publish = 0;
uint8_t         periodic_slot = 0;

///////////////////////////////////////////////////////////////////////////////////////
//////////////////////////////////// PUBLISHER ///////////////////////////////////////
// function called to publish the state of the led (on/off)
boolean publishPWMLightState() {
  boolean ret=false;
  Serial.print("[mqtt] publish PWM state ");
  if (m_pwm_light_state) {
    Serial.println("ON");
    ret = client.publish(build_topic(MQTT_PWM_LIGHT_STATE_TOPIC), STATE_ON, true);
  } else {
    Serial.println("OFF");
    ret = client.publish(build_topic(MQTT_PWM_LIGHT_STATE_TOPIC), STATE_OFF, true);
  }
  if(ret){
    m_published_pwm_light_state = m_pwm_light_state;
  }
  return ret;
}

// function called to publish the brightness of the led
boolean publishPWMLightBrightness() {
  boolean ret=false;
  Serial.print("[mqtt] publish PWM brightness ");
  Serial.println(m_light_brightness);
  snprintf(m_msg_buffer, MSG_BUFFER_SIZE, "%d", m_light_target.r);
  ret = client.publish(build_topic(MQTT_PWM_LIGHT_BRIGHTNESS_STATE_TOPIC), m_msg_buffer, true);
  if(ret){
    m_published_light_brightness = m_light_brightness;
  }
  return ret;
}

// function called to publish the color of the led
boolearn publishPWMRGBColor(){
	boolean ret=false;
	Serial.print("[mqtt] publish PWM color ");
	snprintf(m_msg_buffer, MSG_BUFFER_SIZE, "%d,%d,%d", m_light_target.r, m_light_target.g, m_light_target.b);
	Serial.println(m_msg_buffer);
	ret = client.publish(build_topic(MQTT_PWM_RGB_DIMM_COLOR_STATE_TOPIC), m_msg_buffer, true);
	if(ret){
		m_published_light_color = m_light_target.r + m_light_target.g + m_light_target.b;
	}
	return ret;
}

// function called to publish the state of the led (on/off)
boolean publishSimpleLightState() {
  boolean ret=false;
  Serial.print("[mqtt] publish simple light state ");
  if (m_simple_light_state) {
    Serial.println("ON");
    ret = client.publish(build_topic(MQTT_SIMPLE_LIGHT_STATE_TOPIC), STATE_ON, true);
  } else {
    Serial.println("OFF");
    ret = client.publish(build_topic(MQTT_SIMPLE_LIGHT_STATE_TOPIC), STATE_OFF, true);
  }
  if(ret){
    m_published_simple_light_state = m_simple_light_state;
  };
  return ret;
}

// function called to publish the state of the PIR (on/off)
boolean publishPirState() {
  boolean ret=false;
  Serial.print("[mqtt] publish pir state ");
  if (m_pir_state) {
    Serial.println("motion");
    ret = client.publish(build_topic(MQTT_MOTION_STATUS_TOPIC), STATE_ON, true);
  } else {
    Serial.println("no motion");
    ret = client.publish(build_topic(MQTT_MOTION_STATUS_TOPIC), STATE_OFF, true);
  }
  if(ret){
    m_published_pir_state = m_pir_state;
  } 
  return ret;
}

// function called to publish the brightness of the led
boolean publishTemperature(float temp,int DHT_DS) {  
  if(temp>TEMP_MAX || temp<(-1*TEMP_MAX) || isnan(temp)){
    Serial.print("[mqtt] no publish temp, ");
    if(isnan(temp)){
      Serial.println("nan");  
    } else {
      Serial.print(temp);
      Serial.println(" >TEMP_MAX");
    }
    return false;
  }

  Serial.print("[mqtt] publish ");
  dtostrf(temp, 3, 2, m_msg_buffer);
  if(DHT_DS == DHT_def){
    Serial.print("DHT temp ");
    Serial.println(m_msg_buffer);
    return client.publish(build_topic(MQTT_TEMPARATURE_DHT_TOPIC), m_msg_buffer, true);
  } else {
    Serial.print("DS temp ");
    Serial.println(m_msg_buffer);
    return client.publish(build_topic(MQTT_TEMPARATURE_DS_TOPIC), m_msg_buffer, true);
  }
}

// function called to publish the brightness of the led
boolean publishHumidity(float hum) {
  if(isnan(hum)){
    Serial.println("[mqtt] no publish humidiy");
    return false;
  }
  Serial.print("[mqtt] publish humidiy ");
  dtostrf(hum, 3, 2, m_msg_buffer);
  Serial.println(m_msg_buffer);
  return client.publish(build_topic(MQTT_HUMIDITY_DHT_TOPIC), m_msg_buffer, true);
}

boolean publishRssi(float rssi) {
  Serial.print("[mqtt] publish rssi ");
  dtostrf(rssi, 3, 2, m_msg_buffer);
  Serial.println(m_msg_buffer);
  return client.publish(build_topic(MQTT_RSSI_STATE_TOPIC), m_msg_buffer, true);
}


boolean publishADC(int adc) {
  Serial.print("[mqtt] publish adc ");
  snprintf(m_msg_buffer, MSG_BUFFER_SIZE, "%d", adc);
  Serial.println(m_msg_buffer);
  return client.publish(build_topic(MQTT_ADC_STATE_TOPIC), m_msg_buffer, true);
}
//////////////////////////////////// PUBLISHER ///////////////////////////////////////
///////////////////////////////////////////////////////////////////////////////////////
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
void loop() {
	if (!client.connected()) {
	  reconnect();
	}
	client.loop();
  
	//// dimming active?  ////
	if(millis() <= timer_dimmer_end){
		if(millis() >= timer_dimmer + m_pwm_dimm_time) {
			//Serial.print("DIMMER ");
			timer_dimmer = millis(); // save for next round

			// set new value
			m_light_current.r = map(timer_dimmer, timer_dimmer_start, timer_dimmer_end, m_light_start.r, m_light_target.r);
			m_light_current.g = map(timer_dimmer, timer_dimmer_start, timer_dimmer_end, m_light_start.g, m_light_target.g);
			m_light_current.b = map(timer_dimmer, timer_dimmer_start, timer_dimmer_end, m_light_start.b, m_light_target.b);
      
			//Serial.println(m_light_brightness);
			setPWMLightState(true); // with override 

		}
	}
	//// dimming end ////

	//// publish all state - ONLY after being connected for sure ////

	if (m_simple_light_state != m_published_simple_light_state) {
		if(millis()-timer_last_publish > PUBLISH_TIME_OFFSET){
			publishSimpleLightState();
			timer_last_publish = millis();
		}
	}

	if (m_pwm_light_state != m_published_pwm_light_state) {
		if(millis()-timer_last_publish > PUBLISH_TIME_OFFSET){
			publishPWMLightState();
			timer_last_publish = millis();
		};
	}

	if (m_published_light_brightness != m_light_brightness) { // todo .. fails to publish if we publish to much at the first run ... 
		if(millis()-timer_last_publish > PUBLISH_TIME_OFFSET){
			publishPWMLightBrightness();
			timer_last_publish = millis();
		}
	}
	
	if (m_published_light_color != m_light_target.r + m_light_target.g + m_light_target.b){
		if(millis()-timer_last_publish > PUBLISH_TIME_OFFSET){
			publishPWMRGBColor();
			timer_last_publish = millis();
		}
	}

	if (m_pir_state != m_published_pir_state) {
		if(millis()-timer_last_publish >PUBLISH_TIME_OFFSET){
			publishPirState();  
			timer_last_publish = millis();
		}
	}
	//// publish all state - ONLY after being connected for sure ////


	//// send periodic updates ////
	if ( millis() - updateFastValuesTimer > UPDATE_PERIODIC && millis()-timer_last_publish > PUBLISH_TIME_OFFSET) {
		updateFastValuesTimer = millis();

		if(periodic_slot == 0){
			publishTemperature(getDhtTemp(),DHT_def);
		} else if(periodic_slot == 1){
			publishTemperature(getDsTemp(),DS_def);
		} else if(periodic_slot == 2){
			publishHumidity(getDhtHumidity());
		} else if(periodic_slot == 3){
			publishRssi(WiFi.RSSI());
			digitalWrite(GPIO_D8,HIGH); // prepare for next step ... 6sec on / 100ms would be enough .. 
		} else if(periodic_slot == 4){
			publishADC(analogRead(A0));
			digitalWrite(GPIO_D8,LOW);
		};
		periodic_slot = (periodic_slot+1)%TOTAL_PERIODIC_SLOTS;
	}
	//// send periodic updates  ////
	//// send periodic updates of PIR... just in case  ////
	if ( millis() - updateSlowValuesTimer > UPDATE_PIR && millis()-timer_last_publish > PUBLISH_TIME_OFFSET) {
		updateSlowValuesTimer = millis();
		timer_last_publish = millis();
		publishPirState();  
	}
	//// send periodic updates of PIR ... just in case ////


	/// see if we hold down the button for more then 6sec /// 
	if(counter_button>=10 && millis()-timer_button_down>BUTTON_TIMEOUT){
		Serial.println("[SYS] Rebooting to setup mode");
		delay(200);
		wifiManager.startConfigPortal(CONFIG_SSID); // needs to be tested!
		//ESP.reset(); // reboot and switch to setup mode right after that
	}
	/// see if we hold down the button for more then 6sec /// 
}
////////////////////////////////////////////// LOOP ///////////////////////////////////
///////////////////////////////////////////////////////////////////////////////////////

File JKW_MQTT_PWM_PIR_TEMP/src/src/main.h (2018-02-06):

/*
 * for sonoff touch modules:
 * generic 8266
 * DOUT flash mode!
 * flash 40 mhz, cpu 80mhz
 * flash size 1mb, 64k filesystem
 *
 * QIO > QOUT > DIO > DOUT.
 *
 * Pin1 = 3.3V
 * Pin2 = RxD
 * Pin3 = TxD
 * Pin4 = Masse
 * Pin5 = vorbereitet für GPIO
 */

#ifndef main_h
	#define main_h

	#define FS(x) (__FlashStringHelper *) (x)

#include <ESP8266WiFi.h>
#include <WiFiManager.h> // local modified version          //https://github.com/tzapu/WiFiManager WiFi Configuration Magic
#include <PubSubClient.h>
#include <ESP8266httpUpdate.h>
#include <NeoPixelBus.h>

#include "mqtt_parameter.h"
#include "logging.h"
#include "capability.h"


	class peripheral
	{
public:
		peripheral(){ }

		virtual ~peripheral(){ }

		virtual bool init() = 0;
		virtual bool loop() = 0;
		virtual bool intervall_update(uint8_t slot) = 0;
		virtual uint8_t count_intervall_update()    = 0;
		virtual bool subscribe() = 0;
		virtual bool receive(uint8_t * p_topic, uint8_t * p_payload) = 0;
		virtual bool parse(uint8_t * config) = 0;
		virtual uint8_t * get_key() = 0;
		virtual bool publish()      = 0;
	};

	// ////////////////////////////////////////////////// defines //////////////////////////////////////////////
	#define SERIAL_DEBUG
	#define DIMM_DONE             0 // state defs
	#define DIMM_DIMMING          1 // state defs
	#define DHT_def               1
	#define DS_def                2
	#define TEMP_MAX              70 // DS18B20 repoorts 85.0 on first reading ... for whatever reason
	#define VERSION               "20180206"

	#define CONFIG_SSID           "ESP_CONFIG" // SSID of the configuration mode
	#define MAX_CON_TIME          15           // give up connecting after 15 sec per try
	#define MIN_RECONNECT_TIME    45           // try to reconnect for at least 45 sec, even after power up
	#define CALC_RECONNECT_WEIGHT 5            // add 1 sec of reconnect time per 5 sec that we've been connected previously
	#define MAX_RECONNECT_TIME    20 * 60      // even if we've been happliy connected to this network for weeks: start AP after 20 min of trying to reconnect
	#define MAX_AP_TIME           300          // close AP after 300 sec in config mode and try reconnect


	// capability list
	#define RGB_PWM_BITMASK     1 << 0 // 1
	#define NEOPIXEL_BITMASK    1 << 1 // 2
	#define AVOID_RELAY_BITMASK 1 << 2 // 4
	#define SONOFF_B1_BITMASK   1 << 3 // 8
	#define AITINKER_BITMASK    1 << 4 // 16
	// #define MY9291_BITMASK      1 << 5 // 32
	// #define MY9291_BITMASK      1 << 6 // 64
	// #define MY9291_BITMASK      1 << 7 // 128

	#define T_SL   1
	#define T_PWM  2
	#define T_NEO  3
	#define T_BOne 4
	#define T_AI   5


	#define PINOUT                   "SONOFF"
	#define BUTTON_TIMEOUT           1500 // max 1500ms timeout between each button press to count up (start of config)
	#define BUTTON_DEBOUNCE          400  // ms debouncing for the botton
	#define MSG_BUFFER_SIZE          60   // mqtt messages max char size
	#define TOPIC_BUFFER_SIZE        64   // mqtt topic buffer
	#define PUBLISH_TIME_OFFSET      200  // ms timeout between two publishes

	#define ANIMATION_STEP_TIME      15 // 256 steps per rotation * 15 ms/step = 3.79 sec pro rot
	#define NEOPIXEL_LED_COUNT       24
	#define ANIMATION_OFF            0
	#define ANIMATION_RAINBOW_WHEEL  1
	#define ANIMATION_RAINBOW_SIMPLE 2
	#define ANIMATION_COLOR_WIPE     3

	#define MAX_PERIPHERALS          20


	struct led {
		uint8_t r;
		uint8_t g;
		uint8_t b;
	};

	void callback(char * p_topic, byte * p_payload, unsigned int p_length);
	void reconnect();
	void configModeCallback(WiFiManager * myWiFiManager);
	void saveConfigCallback();
	void loadConfig();
	char * build_topic(const char * topic, uint8_t pc_shall_R_or_S);
	char * build_topic(const char * topic, uint8_t pc_shall_R_or_S, bool with_dev);
	void loadPheripherals(uint8_t * peripherals);
	void setup();
	void loop();
	bool bake(peripheral * p_obj, peripheral ** p_handle, uint8_t * config);


	/*mqtt_parameter_8 m_simple_light_state;
	 * mqtt_parameter_8 m_button_press;
	 * mqtt_parameter_8 m_light_brightness;
	 *
	 * mqtt_parameter_8 m_animation_type; // type 1 = rainbow wheel, 2 = simple rainbow .. see define above
	 * mqtt_parameter_16 m_light_color;
	 */

	// MQTT: topics, constants, etc, send and receive are written from the PC perspective
	//  setter aka the topics we'll subscribe to
	// all topics are used with /r/ or /s/ as prefix by the build_topic function
	// where /s/ topics are send fro, the PC and received here, and /r/ the otherway around
	// light direct
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

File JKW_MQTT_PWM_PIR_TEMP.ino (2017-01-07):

/*
	Highly based on a combination of different version of 
	https://github.com/mertenats/Open-Home-Automation/tree/master/ha_mqtt_binary_sensor_pir
	

	Configuration (HA) : 
	  light:
	    platform: mqtt
	    name: 'Office light'
	    state_topic: 'office/light'
	    command_topic: 'office/light/switch'
	    brightness_state_topic: 'office/light/brightness'
	    brightness_command_topic: 'office/light/brightness/set'
	    optimistic: false

   	Kolja Windeler v0.1 - untested
*/

#include <ESP8266WiFi.h>
#include <PubSubClient.h>
#include <OneWire.h> 


#define MQTT_VERSION MQTT_VERSION_3_1_1
#define DEV "dev1"

// Wifi: SSID and password
const char*             WIFI_SSID         			= "[Redacted]";
const char*             WIFI_PASSWORD     			= "[Redacted]";

// MQTT: ID, server IP, port, username and password
const PROGMEM char*     MQTT_CLIENT_ID    			= "office_light";
const PROGMEM char*     MQTT_SERVER_IP    			= "[Redacted]";
const PROGMEM uint16_t  MQTT_SERVER_PORT  			= 1883;
const PROGMEM char*     MQTT_USER         			= "[Redacted]";
const PROGMEM char*     MQTT_PASSWORD     			= "[Redacted]";

// MQTT: topics
const PROGMEM char*     MQTT_PWM_LIGHT_STATE_TOPIC		= DEV "/PWM_light";			// publish state here
const PROGMEM char*     MQTT_PWM_LIGHT_COMMAND_TOPIC		= DEV "/PWM_light/switch"; 		// get command here

const PROGMEM char*     MQTT_SIMPLE_LIGHT_STATE_TOPIC		= DEV "/simple_light";		// publish state here
const PROGMEM char*     MQTT_SIMPLE_LIGHT_COMMAND_TOPIC		= DEV "/simple_light/switch"; 	// get command here

const PROGMEM char* 	MQTT_MOTION_STATUS_TOPIC		= DEV "/motion/status";		// publish
const PROGMEM char* 	MQTT_TEMPARATURE_TOPIC			= DEV "/temperature";			// publish
const PROGMEM char* 	MQTT_HUMIDITY_TOPIC			= DEV "/humidity";			// publish

const PROGMEM char*     MQTT_PWM_LIGHT_BRIGHTNESS_STATE_TOPIC   = DEV "/PWM_light/brightness";	// publish
const PROGMEM char*     MQTT_PWM_LIGHT_BRIGHTNESS_COMMAND_TOPIC = DEV "/PWM_light/brightness/set";	// set value

// payloads by default (on/off)
const PROGMEM char*     STATE_ON          			= "ON";
const PROGMEM char*     STATE_OFF         			= "OFF";

// variables used to store the statea and the brightness of the light
boolean 		m_pwm_light_state 			= false;
boolean			m_simple_light_state 			= false;
uint8_t 		m_light_brightness			= 255;

// variables used to store the pir state
uint8_t 		m_pir_state 				= LOW; // no motion detected
uint8_t 		m_published_pir_state 			= LOW;
uint8_t 		m_pir_value 				= 0;


// pin used for the led (PWM)
#define PWM_LIGHT_PIN 4
#define SIMPLE_LIGHT_PIN 12 // scheinbar?!
#define BUTTON_INPUT_PIN 0 // ja?
// DHT - D1/GPIO5
#define DHT 1
#define DS 2

#define DHT_DS_MODE DS
#define DHT_PIN 6
// DHT - D1/GPIO5
#define PIR_PIN 5

// buffer used to send/receive data with MQTT
const uint8_t 		MSG_BUFFER_SIZE 	= 60;
char 			m_msg_buffer[MSG_BUFFER_SIZE];

WiFiClient 		wifiClient;
PubSubClient 		client(wifiClient);

//Temperature chip i/o
#if DHT_DS_MODE == DHT
	#include "DHT.h"
	DHT 		dht(DHT_PIN, DHT22); // DHT22
#else
	OneWire 	ds(DHT_PIN);  // on digital pin DHT_PIN
#endif

#define UPDATE_TEMP 60000 // once per minute
uint32_t 		timer	= 0;

//////////////////////////////////// SETTER ///////////////////////////////////////
// function called to adapt the brightness and the state of the led
void setPWMLightState() {
	if (m_pwm_light_state) {
		analogWrite(PWM_LIGHT_PIN, m_light_brightness);
		Serial.print("INFO: PWM Brightness: ");
		Serial.println(m_light_brightness);
	} else {
		analogWrite(PWM_LIGHT_PIN, 0);
		Serial.println("INFO: Turn PWM light off");
	}
}
// function called to adapt the state of the led
void setSimpleLightState() {
	if (m_simple_light_state) {
		digitalWrite(SIMPLE_LIGHT_PIN, HIGH);
		Serial.println("INFO: Simple pin on");
	} else {
		digitalWrite(SIMPLE_LIGHT_PIN, LOW);
		Serial.println("INFO: Simple light off");
	}
}
//////////////////////////////////// SETTER ///////////////////////////////////////

//////////////////////////////////// PUBLISHER ///////////////////////////////////////
// function called to publish the state of the led (on/off)
void publishPWMLightState() {
	if (m_pwm_light_state) {
		client.publish(MQTT_PWM_LIGHT_STATE_TOPIC, STATE_ON, true);
	} else {
		client.publish(MQTT_PWM_LIGHT_STATE_TOPIC, STATE_OFF, true);
	}
}

// function called to publish the brightness of the led
void publishPWMLightBrightness() {
	snprintf(m_msg_buffer, MSG_BUFFER_SIZE, "%d", m_light_brightness);
	client.publish(MQTT_PWM_LIGHT_BRIGHTNESS_STATE_TOPIC, m_msg_buffer, true);
}

// function called to publish the state of the led (on/off)
void publishSimpleLightState() {
	if (m_simple_light_state) {
		client.publish(MQTT_SIMPLE_LIGHT_STATE_TOPIC, STATE_ON, true);
	} else {
		client.publish(MQTT_SIMPLE_LIGHT_STATE_TOPIC, STATE_OFF, true);
	}
}

// function called to publish the state of the PIR (on/off)
void publishPirState() {
	if (m_pir_state) {
		client.publish(MQTT_MOTION_STATUS_TOPIC, STATE_ON, true);
	} else {
		client.publish(MQTT_MOTION_STATUS_TOPIC, STATE_OFF, true);
	}
	m_published_pir_state = m_pir_state;
}

// function called to publish the brightness of the led
void publishTemperature(float temp) {
	dtostrf(temp, 3, 2, m_msg_buffer);
	client.publish(MQTT_TEMPARATURE_TOPIC, m_msg_buffer, true);
}
#if DHT_DS_MODE == DHT 
// function called to publish the brightness of the led
void publishHumidity(float hum) {
	dtostrf(hum, 3, 2, m_msg_buffer);
	client.publish(MQTT_HUMIDITY_TOPIC, m_msg_buffer, true);
}
#endif
//////////////////////////////////// PUBLISHER ///////////////////////////////////////
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

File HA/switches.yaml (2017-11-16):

  - platform: mqtt
    initial: false
    name: "Background"
    command_topic: "gmusic_nice_player"
  
  - platform: template
    switches:
      fernseher:
        value_template: >-
            {% if states.remote.tvhub.attributes.current_activity == 'PowerOff' %}
               off
            {% else %}
               on
            {% endif %}
        turn_on:
          service: remote.turn_on
          entity_id: remote.tvhub
          data:
            activity: 28402151
        turn_off:
          service: script.turn_on
          entity_id: script.seq_tv_off


      next_track:
        value_template: off
        turn_on: 
          service: media_player.media_next_track
          entity_id: media_player.jkw_cast2
        turn_off: 
          service: media_player.media_next_track
          entity_id: media_player.jkw_cast2

      the_buzz:
        value_template: off
        turn_on: 
          service: script.turn_on
          entity_id: script.the_buzz
        turn_off: 
          service: script.turn_on
          entity_id: script.the_buzz

      five_down:
        value_template: off
        turn_on: 
          service: remote.send_command
          entity_id: remote.tvhub
          data:
            command: VolumeDown
            device: 47580278
            num_repeats: 10
            delay_secs: 0.0
        turn_off: 
          service: remote.send_command
          entity_id: remote.tvhub
          data:
            command: VolumeDown
            device: 47580278
            num_repeats: 10
            delay_secs: 0.0


      ten_down:
        value_template: off
        turn_on: 
          service: remote.send_command
          entity_id: remote.tvhub
          data:
            command: VolumeDown
            device: 47580278
            num_repeats: 20
            delay_secs: 0.0
        turn_off: 
          service: remote.send_command
          entity_id: remote.tvhub
          data:
            command: VolumeDown
            device: 47580278
            num_repeats: 20
            delay_secs: 0.0

      five_up:
        value_template: off
        turn_on: 
          service: remote.send_command
          entity_id: remote.tvhub
          data:
            command: Volumeup
            device: 47580278
            num_repeats: 10
            delay_secs: 0.0
        turn_off: 
          service: remote.send_command
          entity_id: remote.tvhub
          data:
            command: Volumeup
            device: 47580278
            num_repeats: 10
            delay_secs: 0.0


      ten_up:
        value_template: off
        turn_on: 
          service: remote.send_command
          entity_id: remote.tvhub
          data:
            command: Volumeup
            device: 47580278
            num_repeats: 20
            delay_secs: 0.0
        turn_off: 
          service: remote.send_command
          entity_id: remote.tvhub
          data:
            command: Volumeup
            device: 47580278
            num_repeats: 20
            delay_secs: 0.0

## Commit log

2017-01-08 added datasheet, corrected pinout
    [JKW_MQTT_PWM_PIR_TEMP.ino]
2017-01-10 first working verion, whird pin isses
2017-01-11 Fixed missing "D" for pins
    [JKW_MQTT_PWM_PIR_TEMP.ino]
2017-01-12 simplified button pushs
2017-01-12 return correct pwm brightness after turn pwm on again
    [JKW_MQTT_PWM_PIR_TEMP.ino]
2017-01-12 fixed pwm value reporting
    [JKW_MQTT_PWM_PIR_TEMP.ino]
2017-01-12 dimm on and dimm off with saving of old existing value added, publish buggy
    [JKW_MQTT_PWM_PIR_TEMP.ino]
2017-01-15 added pcb files
    [esp_all.brd, esp_all.sch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]
2017-01-16 removed v1
    [esp_all.brd, esp_all.sch]
2017-01-16 Improved ESP readability
    [esp_all2.brd, esp_all2.sch]
2017-01-18 added excel version of pinout
    [pinout.xlsx]
2017-01-18 added dev2 temperature
2017-01-18 added republish for wrong HA state
    [JKW_MQTT_PWM_PIR_TEMP.ino]
2017-01-18 activated interrupt earier to make sure we can use the button even with no connection
2017-01-19 added switch for my own hardware
2017-01-20 added http update server and arduino OTA lib, changed pinout
    [pinout.xlsx]
2017-01-20 added FW update button
2017-01-20 added wifi OTA support, changed pin def from d to gpio number
2017-01-20 added D buttons as comment
2017-01-21 made sure that config IP is fixed
    [JKW_MQTT_PWM_PIR_TEMP.ino]
2017-01-22 fixed order of fail and pass and added send :|
    [JKW_MQTT_PWM_PIR_TEMP.ino]
2017-02-01 added v3
    [esp_all2.GBL, esp_all2.GBO, esp_all2.GBP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]
2017-02-03 updated schematic
    [esp_all3.brd, esp_all3.sch, pinout.xlsx]
2017-02-06 added LDO
    [esp_all3.brd, esp_all3.sch]
2017-02-13 added double footprint for power transistor
    [esp_all3.brd, esp_all3.sch]
2017-02-13 flipped PIR
    [esp_all3.brd, esp_all3.sch]
2017-02-14 added more transistors
    [esp_all3.brd, esp_all3.sch]
2017-02-15 added jumper
    [esp_all3.brd, esp_all3.sch]
2017-03-03 adapted pinout to v3 pf the pcb
2017-03-03 adapted v3 pinout
    [pinout.xlsx]
2017-03-04 added dev16 and a template sensor
2017-03-04 added 1min template sensor
2017-03-06 added v4, with i2c
    [esp_all3.brd, esp_all3.sch, esp_all4.brd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]
2017-03-06 fixed LDO
    [esp_all4.brd, esp_all4.sch]
2017-03-07 added voltage reg
    [esp_all4.brd, esp_all4.sch]
2017-03-08 added tiny board
    [esp_tiny1.GBL, esp_tiny1.GBO, esp_tiny1.GBP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]
2017-03-09 fixed i2c error, thanks to michell
    [esp_tiny1.brd, esp_tiny1.sch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]
2017-10-08 added button
2017-10-09 Removed all temp file
    [esp_tiny2.brd, esp_tiny2.sch]
2017-10-21 added set value method, added CLI id attached to SSID and in the menu
2017-10-23 add MQTT incoming print fixed reset after config only switch on light after power down add animation support for my9291 (untested)
    [main.cpp]
2017-10-24 ensured that we're connect to wifi (not the case after config AP mode)
2017-10-25 Dimming improvement Fixed: Made sure dimm reaches end Enhancement: don't send mqtt messages during dimm
    [main.cpp, main.h]
2017-11-06 dimming not working as of now
    [PWM.cpp, light.cpp, light.h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]
2017-11-11 make sure right topics are reported to HA to set interface correct
    [light.cpp]
2017-11-12 general trace concept working, beautification and on/off missing
    [logging.cpp]
2017-11-12 added trace
2017-11-21 added 2nd slot for adc to keep the gpio off as long as possible
2017-11-21 readded imidiate switching of light on button push
2017-12-10 added second and thrid instance to PIR and PWM
2017-12-17 removed interrupt from std classes
2017-12-17 changed Slot to be unit based
2017-12-20 added 5 pin pwm
2017-12-27 Removed checkboxes and readded capability string, also skipped capability reading from console
    [main.cpp]
2017-12-28 Fixed bug with too many parameter in wifimanager
    [main.cpp, main.h]
2018-01-07 chaned resistor according to measurements
2018-01-13 added 1s,2s,3s button hold topics
2018-01-20 fixed getting SSID and password form wifimanager, publish MAC
    [main.cpp, main.h]
2018-02-22 works but interrupts can kill it
2018-02-27 Added Reset serial line cmd and TOPIC_OTA
    [logging.cpp]
2018-02-27 Disconnect on blacklist fails, long message handling, OTA via MQTT
    [main.cpp, main.h]
2018-02-27 cleanup, added release, corrected filename
    [main.h]

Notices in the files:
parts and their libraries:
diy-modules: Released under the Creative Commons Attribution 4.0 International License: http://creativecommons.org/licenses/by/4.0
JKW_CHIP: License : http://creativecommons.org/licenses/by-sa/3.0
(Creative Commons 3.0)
